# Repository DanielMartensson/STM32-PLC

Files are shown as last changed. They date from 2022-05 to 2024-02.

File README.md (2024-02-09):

# STM32 PLC

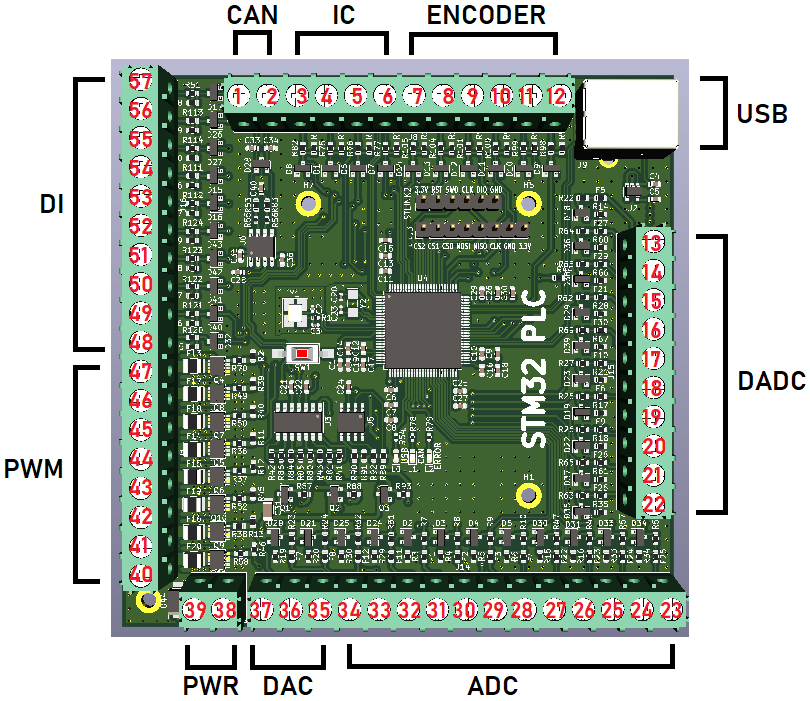
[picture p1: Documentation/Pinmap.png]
a


This project is a PCB bord that has the following measurement and control input/output:

 * 12 x ADC at 16-bit resolution for 0-20mA input with programmable gain
 * 5 x Differential ADC at 16-bit for 0-20mA input with programmable gain
 * 3 x DAC at 12-bit with 0-20mA output
 * 8 x PWM for 0-2.2A with N-channel MOSFET
 * 10 x Digital Input
 * 1 x CAN-bus channel
 * 4 x Input Capture for 0 kHz to 10kHz
 * 3 x Encoder for -32768 to 32767 pulses
 * 1 x USB port for connecting with [OpenSourceLogger](https://github.com/DanielMartensson/OpenSourceLogger) and [GoobySoft](https://github.com/DanielMartensson/GoobySoft)
 * 1 x SPI with 3 chip select for ILI9341 LCD with touch
 * 1 x ST-Link V2 connection
 * 1 x RTC clock with two alarms A(date) and B(week day) and a battery holder so the RTC remembers the date and time

## Protection 
 * All ADC, Digital Input, Differential ADC, Input Capture and Encoder are high voltage protected with PTC(fall current 30mA) fuse + 3.6v zener diode.
 * All PWM and DAC are high voltage protected with N-channel MOSFET and PNP-transistor and OP-amp. 
 * The CAN-bus channel is high voltage peak protected for 3000V under a short time with a TVS-diode. The CAN-bus transmitter itself can hold against -14V to +14V, but the TVS-diode has a limit around 6V. 

## Documentation
The documentation for the pin map can be found in the `Documentation` folder. Also all the article numbers for each component can be found in at the `DAC ADC PWM IO.sch` file in the `PCB` folder. Just double click on a PCB symbol and see the `Mouser Electronics` article number of the electrical component. 

## Calibration
Yes, it's possible to set the calibration to each input in this project. You need to have the ILI9341 touch LCD with SPI bus. Open the `STM32 PLC Pinouts.pdf` and see the connection for the LCD. You can also set the PWM frequency and analog input gain for the ADC and Differential ADC at 16-bit. 

## SAE J1939
The STM32 PLC has internal SAE J1939 protocol. Made from [Open-SAE-J1939](https://github.com/DanielMartensson/Open-SAE-J1939) repository.

## OpenSourceLogger
This is a QT C++ software that you can connect to your STM32 PLC board via the USB and then you can send signals from OpenSourceLogger and recieve signals.
OpenSourceLogger is a very easy to use logging and controlling software and it stores data at a SQL server. 

## GoobySoft
This is a ImGui C++ project that do the same as OpenSourceLogger, but it's much better and have more features. The reason why I moved away from QT C++ to ImGui C++ is because
it's much easier to write a GUI application in C++ by using ImGui instead of QT. With QT, you are stuck with object oriented programming. Everything is a class. 
But for ImGui, you can choose which type of lever you want to code, I prefer C-style C++ code with a small dose of object oriented programming (if needed). 

Consider that I will work on GoobySoft instead of OpenSourceLogger.

## Program 
The STM32 PLC has a lot of functions you can select by touching the LCD. 

 * A:Show measurement and time
 * B:Set analog gain
 * C:Set PWM frequencies
 * D:Set analog input calibration
 * E:Set pulses per encoder revolution
 * F:Set date and time and alarm
 * G:Do a PGN request
 * H:Show ECU addresses
 * I:Commanded address
 * J:Show this ECU DM1 codes
 * K:Show other ECU DM1 codes
 * L:Show this ECU DM2 codes
 * M:Show other ECU DM2 codes
 * N:Show this ECU name
 * O:Show other ECU name
 * P:Show this ECU identifications
 * Q:Show other ECU identifications
 * R:SAE J1939 Auxiliary valve command
 * S:Analog in to PWM
 * T:Analog in to analog out
 * U:About STM32 PLC

## How to build this STM32 PLC

 1. Download this repository
 2. Download & Install KiCad
 3. Open the `PCB` folder and open the `.pro` file with KiCAD and greate a `gerber` file of your own choice
 4. Go to your PCB manufacturer and give them the `gerber` file and let them produce the board for you
 5. Order the eletrical components from `Mouser Electronics`
 6. Once you have the eletrical components and your PCB board, it's time to solder them.
 7. Once the PCB board is finished, then install STM32CubeIDE
 8. Open the `Code` project and import the `.ioc` project file using STM32CubeIDE
 9. Flash the board with the `C` code by using ST-Link V2 connection
 10. Connect the ILI9431 touch LCD and then you are done!

## Software used

 * KiCAD: 6.0.7
 * STM32CubeIDE 1.10.1

## Status of the project
It's done. I don't plan to update this project. Everything is working and it will remain that way.

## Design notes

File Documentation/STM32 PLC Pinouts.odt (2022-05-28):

STM32 PLC Pinouts

# Pin definitions

- CAN = CAN bus channel at 250 kB/s baud rate
- IC = Input capture pulse measurement
- Encoder = Encoder pulse measurement
- DADC = Differential Analog to Digital Converter
- ADC = Analog to Digital Converter
- DAC = Digital to Analog Converter
- PWR = Power supply
- PWM = Pulse with modulation
- DI = Digital input

Pin number | Iinput/Output | Name | Max voltage | Min voltage | Comment | Purpose
1 | Both | CAN High | 14V | -15V | TVS diodes for 30kV | CAN communication
2 | Both | CAN Low | 14V | -15V | TVS diodes for 30kV | CAN communication
3 | Input | IC 0 | 30V | -1V | 16 -bit resolution | Frequency 0 Hz to 10 kHz
4 | Input | IC 1 | 30V | -1V | 16 -bit resolution | Frequency 0 Hz to 10 kHz
5 | Input | IC 2 | 30V | -1V | 16 -bit resolution | Frequency 0 Hz to 10 kHz
6 | Input | IC 3 | 30V | -1V | 16 -bit resolution | Frequency 0 Hz to 10 kHz
7 | Input | Encoder 0 + | 30V | -1V | 16 -bit resolution | Counting -32768 to 32767
8 | Input | Encoder 0 - | 30V | -1V | 16 -bit resolution | Counting -32768 to 32767
9 | Input | Encoder 1 + | 30V | -1V | 16 -bit resolution | Counting -32768 to 32767
10 | Input | Encoder 1 - | 30V | -1V | 16 -bit resolution | Counting -32768 to 32767
11 | Input | Encoder 2 + | 30V | -1V | 16 -bit resolution | Counting -32768 to 32767
12 | Input | Encoder 2 - | 30V | -1V | 16 -bit resolution | Counting -32768 to 32767
13 | Input | DADC 4 - | 30V | -1V | PTC 30mA protection | Measuring -32768 to 32767
14 | Input | DADC 4 + | 30V | -1V | PTC 30mA protection | Measuring -32768 to 32767
15 | Input | DADC 3 - | 30V | -1V | PTC 30mA protection | Measuring -32768 to 32767
16 | Input | DADC 3 + | 30V | -1V | PTC 30mA protection | Measuring -32768 to 32767
17 | Input | DADC 2 - | 30V | -1V | PTC 30mA protection | Measuring -32768 to 32767
18 | Input | DADC 2 + | 30V | -1V | PTC 30mA protection | Measuring -32768 to 32767
19 | Input | DADC 1 - | 30V | -1V | PTC 30mA protection | Measuring -32768 to 32767
20 | Input | DADC 1 + | 30V | -1V | PTC 30mA protection | Measuring -32768 to 32767
21 | Input | DADC 0 - | 30V | -1V | PTC 30mA protection | Measuring -32768 to 32767
22 | Input | DADC 0 + | 30V | -1V | PTC 30mA protection | Measuring -32768 to 32767
23 | Input | ADC 11 | 30V | -1V | PTC 30mA protection | Measuring 0 to 65535
24 | Input | ADC 10 | 30V | -1V | PTC 30mA protection | Measuring 0 to 65535
25 | Input | ADC 9 | 30V | -1V | PTC 30mA protection | Measuring 0 to 65535
26 | Input | ADC 8 | 30V | -1V | PTC 30mA protection | Measuring 0 to 65535
27 | Input | ADC 7 | 30V | -1V | PTC 30mA protection | Measuring 0 to 65535
28 | Input | ADC 6 | 30V | -1V | PTC 30mA protection | Measuring 0 to 65535
29 | Input | ADC 5 | 30V | -1V | PTC 30mA protection | Measuring 0 to 65535
30 | Input | ADC 4 | 30V | -1V | PTC 30mA protection | Measuring 0 to 65535
31 | Input | ADC 3 | 30V | -1V | PTC 30mA protection | Measuring 0 to 65535
32 | Input | ADC 2 | 30V | -1V | PTC 30mA protection | Measuring 0 to 65535
33 | Input | ADC 1 | 30V | -1V | PTC 30mA protection | Measuring 0 to 65535
34 | Input | ADC 0 | 30V | -1V | PTC 30mA protection | Measuring 0 to 65535
35 | Output | DAC 2 | 30V | -1V | 12-bit resolution | 0 to 20mA output
36 | Output | DAC 1 | 30V | -1V | 12-bit resolution | 0 to 20mA output
37 | Output | DAC 0 | 30V | -1V | 12-bit resolution | 0 to 20mA output
38 | Input | VDC | 32V | -1V | | Power supply for the 0 to 20 mA output
39 | Output | GND | 0V | 0V | | Ground
40 | Input(Open drain) | PWM 7 | 30V | -1V | Use protection diode if solenoid is applied | MOSFET N-Channel PWM open drain
41 | Input(Open drain) | PWM 6 | 30V | -1V | Use protection diode if solenoid is applied | MOSFET N-Channel PWM open drain
42 | Input(Open drain) | PWM 5 | 30V | -1V | Use protection diode if solenoid is applied | MOSFET N-Channel PWM open drain
43 | Input(Open drain) | PWM 4 | 30V | -1V | Use protection diode if solenoid is applied | MOSFET N-Channel PWM open drain
44 | Input(Open drain) | PWM 3 | 30V | -1V | Use protection diode if solenoid is applied | MOSFET N-Channel PWM open drain
45 | Input(Open drain) | PWM 2 | 30V | -1V | Use protection diode if solenoid is applied | MOSFET N-Channel PWM open drain
46 | Input(Open drain) | PWM 1 | 30V | -1V | Use protection diode if solenoid is applied | MOSFET N-Channel PWM open drain
47 | Input(Open drain) | PWM 0 | 30V | -1V | Use protection diode if solenoid is applied | MOSFET N-Channel PWM open drain
48 | Input | DI 9 | 30V | -1V | Zener diode protection | Measuring 0 to 1
49 | Input | DI 8 | 30V | -1V | | Measuring 0 to 1
50 | Input | DI 7 | 30V | -1V | | Measuring 0 to 1
51 | Input | DI 6 | 30V | -1V | | Measuring 0 to 1
52 | Input | DI 5 | 30V | -1V | | Measuring 0 to 1
53 | Input | DI 4 | 30V | -1V | | Measuring 0 to 1
54 | Input | DI 3 | 30V | -1V | | Measuring 0 to 1
55 | Input | DI 2 | 30V | -1V | | Measuring 0 to 1
56 | Input | DI 1 | 30V | -1V | | Measuring 0 to 1
57 | Input | DI 0 | 30V | -1V | | Measuring 0 to 1


# LCD ILI9341 with SPI bus

Notice that the CLK for the ST-LINK V2 and the other CLK pin is not the same! The other CLK pin is the SPI clock pin.

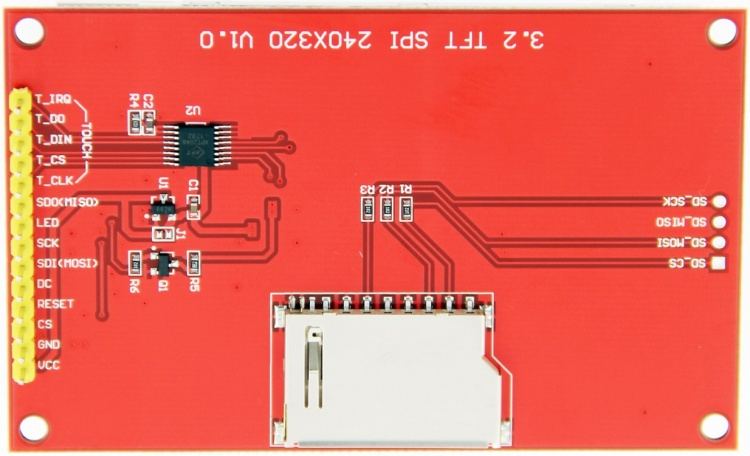
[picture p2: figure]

Connect | To | Comment
T_IRQ | | Leave floating
T_DO | SDO<MISO> | On the LCD
D_DIN | SDI<MOSI> | On the LCD
T_CS | CS2 | On the STM32 PLC
T_CLK | SCK | On the LCD
SDO<MISO> | MISO | On the STM32 PLC
LED | VCC | On the LCD
SCK | CLK | On the STM32 PLC
SDI<MOSI> | MOSI | On the STM32 PLC
DC | CS1 | On the STM32 PLC
RESET | VCC | On the LCD
CS | CS0 | On the STM32 PLC
GND | GND | On the STM32 PLC
VCC | 3.3V | On the STM32 PLC

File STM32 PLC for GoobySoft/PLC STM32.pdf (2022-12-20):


20/12/2022

PLC STM32 Project
Configuration Report

## 1. Description

### 1.1. Project

Project Name | PLC STM32
Board Name | custom
Generated with: | STM32CubeMX 6.6.1
Date | 12/20/2022

### 1.2. MCU

MCU Series | STM32F3
MCU Line | STM32F373
MCU name | STM32F373VBTx
MCU Package | LQFP100
MCU Pin number | 100

### 1.3. Core(s) information

Core(s) | Arm Cortex-M4

## 2. Pinout Configuration

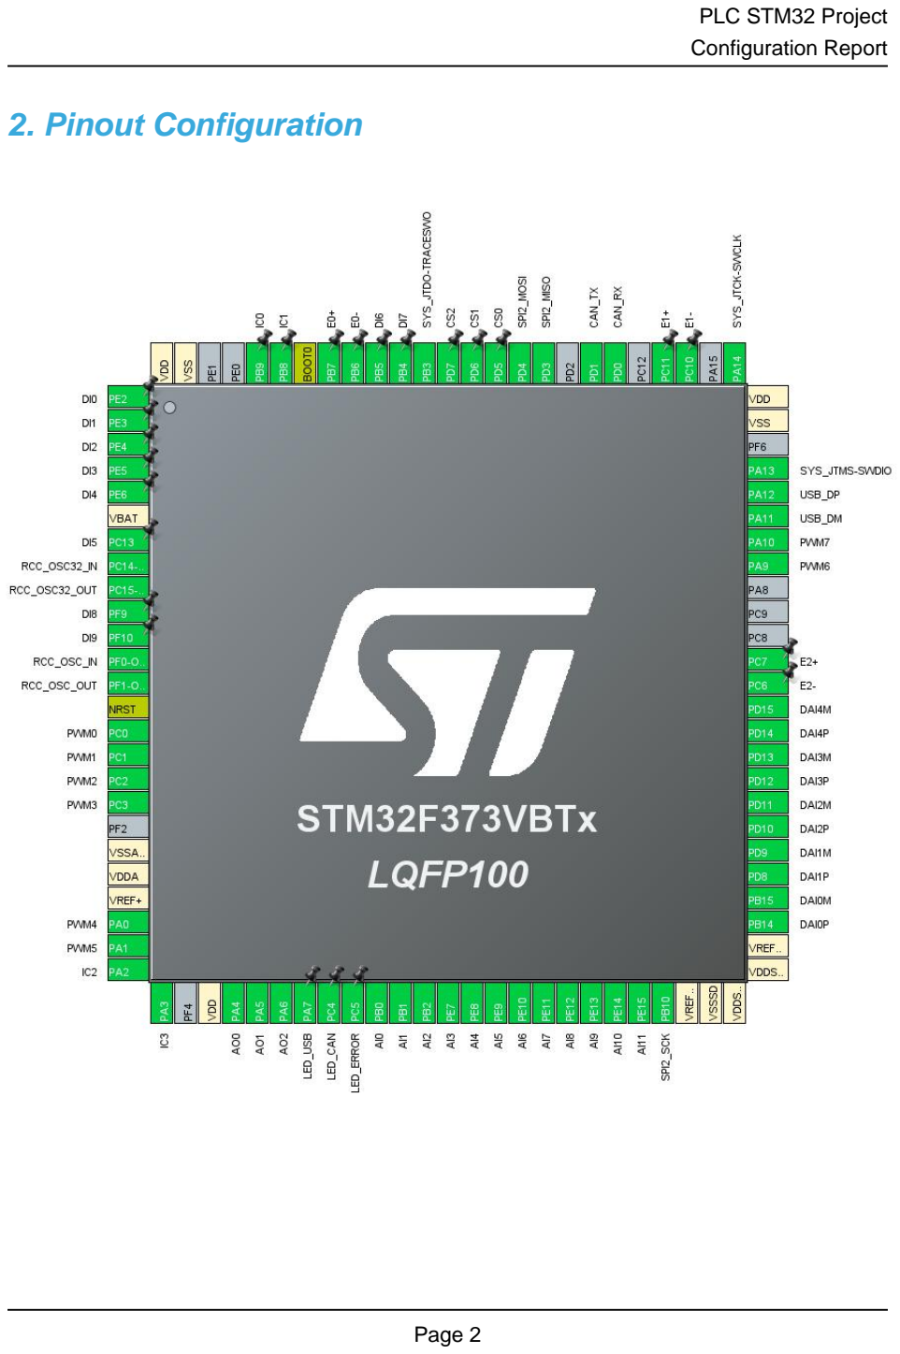
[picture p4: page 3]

## 3. Pins Configuration

Pin Number LQFP100 | Pin Name (function after reset) | Pin Type | Alternate Function(s) | Label
1 | PE2 * | I/O | GPIO_Input | DI0
2 | PE3 * | I/O | GPIO_Input | DI1
3 | PE4 * | I/O | GPIO_Input | DI2
4 | PE5 * | I/O | GPIO_Input | DI3
5 | PE6 * | I/O | GPIO_Input | DI4
6 | VBAT | Power
7 | PC13 * | I/O | GPIO_Input | DI5
8 | PC14-OSC32_IN | I/O | RCC_OSC32_IN
9 | PC15-OSC32_OUT | I/O | RCC_OSC32_OUT
10 | PF9 * | I/O | GPIO_Input | DI8
11 | PF10 * | I/O | GPIO_Input | DI9
12 | PF0-OSC_IN | I/O | RCC_OSC_IN
13 | PF1-OSC_OUT | I/O | RCC_OSC_OUT
14 | NRST | Reset
15 | PC0 | I/O | TIM5_CH1 | PWM0
16 | PC1 | I/O | TIM5_CH2 | PWM1
17 | PC2 | I/O | TIM5_CH3 | PWM2
18 | PC3 | I/O | TIM5_CH4 | PWM3
20 | VSSA/VREF- | Power
21 | VDDA | Power
22 | VREF+ | Power
23 | PA0 | I/O | TIM2_CH1 | PWM4
24 | PA1 | I/O | TIM2_CH2 | PWM5
25 | PA2 | I/O | TIM15_CH1 | IC2
26 | PA3 | I/O | TIM15_CH2 | IC3
28 | VDD | Power
29 | PA4 | I/O | DAC1_OUT1 | AO0
30 | PA5 | I/O | DAC1_OUT2 | AO1
31 | PA6 | I/O | DAC2_OUT1 | AO2
32 | PA7 * | I/O | GPIO_Output | LED_USB
33 | PC4 * | I/O | GPIO_Output | LED_CAN
34 | PC5 * | I/O | GPIO_Output | LED_ERROR
35 | PB0 | I/O | SDADC1_AIN6P | AI0
36 | PB1 | I/O | SDADC1_AIN5P | AI1
37 | PB2 | I/O | SDADC1_AIN4P | AI2
38 | PE7 | I/O | SDADC1_AIN3P | AI3

Pin Number LQFP100 | Pin Name (function after reset) | Pin Type | Alternate Function(s) | Label
39 | PE8 | I/O | SDADC1_AIN8P | AI4
40 | PE9 | I/O | SDADC1_AIN7P | AI5
41 | PE10 | I/O | SDADC1_AIN2P | AI6
42 | PE11 | I/O | SDADC1_AIN1P | AI7
43 | PE12 | I/O | SDADC1_AIN0P | AI8
44 | PE13 | I/O | SDADC2_AIN2P | AI9
45 | PE14 | I/O | SDADC2_AIN1P | AI10
46 | PE15 | I/O | SDADC2_AIN0P | AI11
47 | PB10 | I/O | SPI2_SCK
48 | VREFSD- | Power
49 | VSSSD | Power
50 | VDDSD12 | Power
51 | VDDSD3 | Power
52 | VREFSD+ | Power
53 | PB14 | I/O | SDADC3_AIN8P | DAI0P
54 | PB15 | I/O | SDADC3_AIN8M | DAI0M
55 | PD8 | I/O | SDADC3_AIN6P | DAI1P
56 | PD9 | I/O | SDADC3_AIN6M | DAI1M
57 | PD10 | I/O | SDADC3_AIN4P | DAI2P
58 | PD11 | I/O | SDADC3_AIN4M | DAI2M
59 | PD12 | I/O | SDADC3_AIN2P | DAI3P
60 | PD13 | I/O | SDADC3_AIN2M | DAI3M
61 | PD14 | I/O | SDADC3_AIN0P | DAI4P
62 | PD15 | I/O | SDADC3_AIN0M | DAI4M
63 | PC6 | I/O | TIM3_CH1 | E2-
64 | PC7 | I/O | TIM3_CH2 | E2+
68 | PA9 | I/O | TIM2_CH3 | PWM6
69 | PA10 | I/O | TIM2_CH4 | PWM7
70 | PA11 | I/O | USB_DM
71 | PA12 | I/O | USB_DP
72 | PA13 | I/O | SYS_JTMS-SWDIO
74 | VSS | Power
75 | VDD | Power
76 | PA14 | I/O | SYS_JTCK-SWCLK
78 | PC10 | I/O | TIM19_CH1 | E1-
79 | PC11 | I/O | TIM19_CH2 | E1+
81 | PD0 | I/O | CAN_RX
82 | PD1 | I/O | CAN_TX
84 | PD3 | I/O | SPI2_MISO

Pin Number LQFP100 | Pin Name (function after reset) | Pin Type | Alternate Function(s) | Label
85 | PD4 | I/O | SPI2_MOSI
86 | PD5 * | I/O | GPIO_Output | CS0
87 | PD6 * | I/O | GPIO_Output | CS1
88 | PD7 * | I/O | GPIO_Output | CS2
89 | PB3 | I/O | SYS_JTDO-TRACESWO
90 | PB4 * | I/O | GPIO_Input | DI7
91 | PB5 * | I/O | GPIO_Input | DI6
92 | PB6 | I/O | TIM4_CH1 | E0-
93 | PB7 | I/O | TIM4_CH2 | E0+
94 | BOOT0 | Boot
95 | PB8 | I/O | TIM16_CH1 | IC1
96 | PB9 | I/O | TIM17_CH1 | IC0
99 | VSS | Power
100 | VDD | Power

* The pin is affected with an I/O function

## 4. Clock Tree Configuration

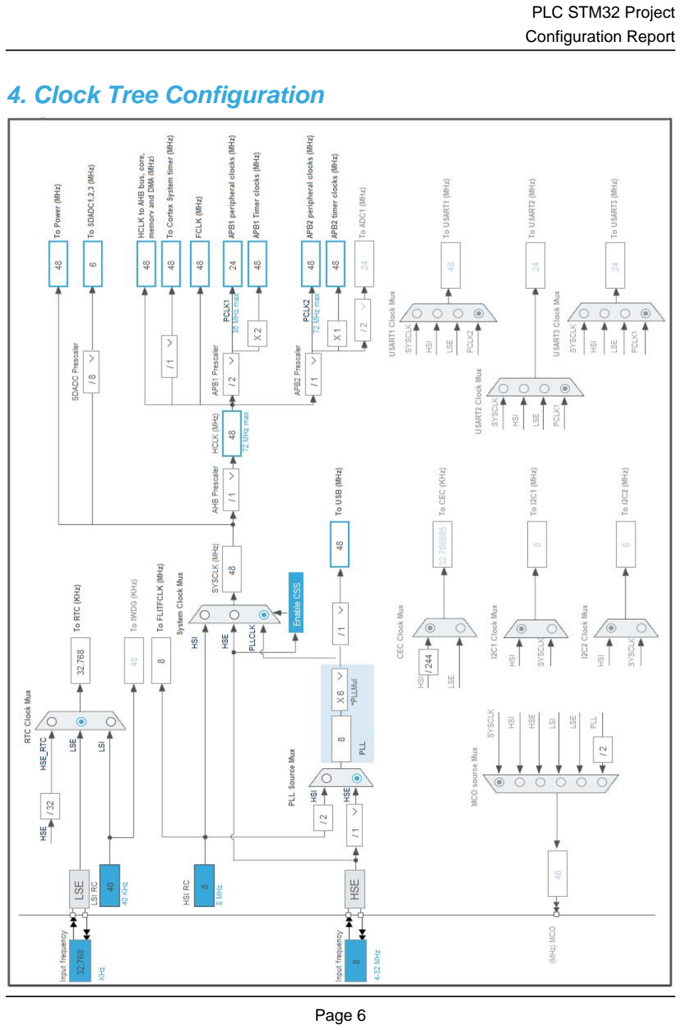
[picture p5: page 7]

## 5. Software Project

### 5.1. Project Settings

Name | Value
Project Name | PLC STM32
Project Folder | C:\Users\dmn\STM32Cube\Projekt\PLC STM32
Toolchain / IDE | STM32CubeIDE
Firmware Package Name and Version | STM32Cube FW_F3 V1.11.3
Application Structure | Advanced
Generate Under Root | Yes
Do not generate the main() | No
Minimum Heap Size | 0x200
Minimum Stack Size | 0x400

### 5.2. Code Generation Settings

Name | Value
STM32Cube MCU packages and embedded software | Copy only the necessary library files
Generate peripheral initialization as a pair of '.c/.h' files | No
Backup previously generated files when re-generating | No
Keep User Code when re-generating | Yes
Delete previously generated files when not re-generated | Yes
Set all free pins as analog (to optimize the power consumption) | No
Enable Full Assert | No

### 5.3. Advanced Settings - Generated Function Calls

Rank | Function Name | Peripheral Instance Name
1 | MX_GPIO_Init | GPIO
2 | SystemClock_Config | RCC
3 | MX_DAC1_Init | DAC1
4 | MX_DAC2_Init | DAC2
5 | MX_TIM2_Init | TIM2
6 | MX_TIM5_Init | TIM5
7 | MX_TIM4_Init | TIM4
8 | MX_SDADC1_Init | SDADC1
9 | MX_SDADC2_Init | SDADC2
10 | MX_SDADC3_Init | SDADC3
11 | MX_CAN_Init | CAN

Rank | Function Name | Peripheral Instance Name
12 | MX_TIM6_Init | TIM6
13 | MX_TIM12_Init | TIM12
14 | MX_TIM13_Init | TIM13
15 | MX_TIM16_Init | TIM16
16 | MX_USB_DEVICE_Init | USB_DEVICE
17 | MX_TIM17_Init | TIM17
18 | MX_DMA_Init | DMA
19 | MX_TIM19_Init | TIM19
20 | MX_TIM3_Init | TIM3
21 | MX_TIM15_Init | TIM15
22 | MX_SPI2_Init | SPI2
23 | MX_RTC_Init | RTC

## 6. Power Consumption Calculator report

### 6.1. Microcontroller Selection

Series | STM32F3
Line | STM32F373
MCU | STM32F373VBTx
Datasheet | DS8845_Rev7

### 6.2. Parameter Selection

Temperature | 25
Vdd | 3.6

### 6.3. Battery Selection

Battery | Li-SOCL2(A3400)
Capacity | 3400.0 mAh
Self Discharge | 0.08 %/month
Nominal Voltage | 3.6 V
Max Cont Current | 100.0 mA
Max Pulse Current | 200.0 mA
Cells in series | 1
Cells in parallel | 1

### 6.4. Sequence

Step | Step1 | Step2
Mode | RUN | STOP
Vdd | 3.6 | 3.6
Voltage Source | Battery | Battery
Range | No Scale | No Scale
Fetch Type | RAM | n/a
CPU Frequency | 72 MHz | 0 Hz
Clock Configuration | HSEBYP PLL | Regulator_LP
Clock Source Frequency | 8 MHz | 0 Hz
Peripherals
Additional Cons. | 0 mA | 0 mA
Average Current | 30.25 mA | 10.9 µA
Duration | 0.1 ms | 0.9 ms
DMIPS | 90.0 | 0.0
Ta Max | 99.99 | 105
Category | In DS Table | In DS Table

### 6.5. Results

Sequence Time | 1 ms | Average Current | 3.03 mA
Battery Life | 1 month, 16 days, 4 hours | Average DMIPS | 90.0 DMIPS

### 6.6. Chart

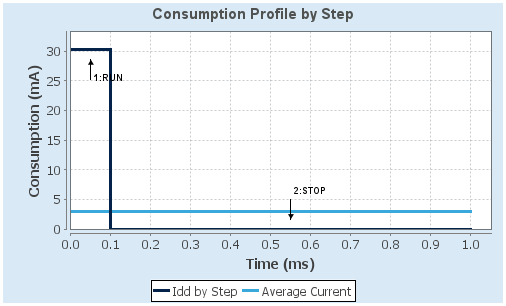
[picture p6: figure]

## 7. Peripherals and Middlewares Configuration

### 7.1. CAN

mode: Activated
7.1.1. Parameter Settings:

Bit Timings Parameters:

Prescaler (for Time Quantum) | 12 *
Time Quantum | 500.0 *
Time Quanta in Bit Segment 1 | 6 Times *
Time Quanta in Bit Segment 2 | 1 Time
Time for one Bit | 4000 *
Baud Rate | 250000 *
ReSynchronization Jump Width | 1 Time
Basic Parameters:
Time Triggered Communication Mode | Disable
Automatic Bus-Off Management | Disable
Automatic Wake-Up Mode | Disable
Automatic Retransmission | Disable
Receive Fifo Locked Mode | Disable
Transmit Fifo Priority | Disable
Advanced Parameters:
Operating Mode | Normal

### 7.2. DAC1

mode: OUT1 Configuration
mode: OUT2 Configuration
7.2.1. Parameter Settings:

DAC Out1 Settings:

Output Buffer | Enable
Trigger | Timer 6 Trigger Out event *
Wave generation mode | Disabled
DAC Out2 Settings:
Output Buffer | Enable
Trigger | Timer 6 Trigger Out event *
Wave generation mode | Disabled

### 7.3. DAC2

mode: OUT1 Configuration
7.3.1. Parameter Settings:

DAC Out1 Settings:

Output Buffer | Enable
Trigger | Timer 6 Trigger Out event *

### 7.4. RCC

High Speed Clock (HSE): Crystal/Ceramic Resonator Low Speed Clock (LSE) : Crystal/Ceramic Resonator
7.4.1. Parameter Settings:

System Parameters:

VDD voltage (V) | 3.3
Prefetch Buffer | Enabled
Flash Latency(WS) | 1 WS (2 CPU cycle)
RCC Parameters:
HSI Calibration Value | 16
HSE Startup Timout Value (ms) | 100
LSE Startup Timout Value (ms) | 10000 *
LSE Drive Capability | LSE oscillator low drive capability

### 7.5. RTC

mode: Activate Clock Source
mode: Activate Calendar
Alarm A: Internal Alarm A
Alarm B: Internal Alarm B
7.5.1. Parameter Settings:

General:

Hour Format | Hourformat 24
Asynchronous Predivider value | 127

Synchronous Predivider value | 255
Calendar Time:
Data Format | BCD data format
Hours | 0
Minutes | 0
Seconds | 0
Day Light Saving: value of hour adjustment | Daylightsaving None
Store Operation | Storeoperation Reset
Calendar Date:
Week Day | Monday
Month | January
Date | 1
Year | 0
Alarm A:
Hours | 0
Minutes | 0
Seconds | 0
Sub Seconds | 0
Alarm Mask Date Week day | Disable
Alarm Mask Hours | Disable
Alarm Mask Minutes | Disable
Alarm Mask Seconds | Disable
Alarm Sub Second Mask | All Alarm SS fields are masked.
Alarm Date Week Day Sel | Date
Alarm Date | 1
Alarm B:
Hours | 0
Minutes | 0
Seconds | 0
Sub Seconds | 0
Alarm Mask Date Week day | Disable
Alarm Mask Hours | Disable
Alarm Mask Minutes | Disable
Alarm Mask Seconds | Disable
Alarm Sub Second Mask | All Alarm SS fields are masked.
Alarm Date Week Day Sel | Weekday *
Alarm Week Day | Monday

### 7.6. SDADC1

IN0: IN0-Single-Ended zero reference IN1: IN1-Single-Ended zero reference IN2: IN2-Single-Ended zero reference IN3: IN3-Single-Ended zero reference IN4: IN4-Single-Ended zero reference IN5: IN5-Single-Ended zero reference IN6: IN6-Single-Ended zero reference IN7: IN7-Single-Ended zero reference IN8: IN8-Single-Ended zero reference mode: Conversion Configuration 0 mode: Conversion Configuration 1 mode: Conversion Configuration 2
7.6.1. Parameter Settings:

General Settings:

Low Power Mode | None
Fast Conversion Mode | Disable
Slow Clock Mode | Disable
Reference Voltage | Forced externally using VREF pin
Conversion Configuration 0:
Input Mode | Single-ended zero-volt reference mode *
Gain | equal to 1
Common Mode | SDADC VSSA
Offset | 0
Conversion Configuration 1:
Input Mode | Single-ended zero-volt reference mode *
Gain | equal to 1
Common Mode | SDADC VSSA
Offset | 0
Conversion Configuration 2:
Input Mode | Single-ended zero-volt reference mode *
Gain | equal to 1
Common Mode | SDADC VSSA
Offset | 0
SDADC Regular Conversions Settings:
Enable Regular Conversion | Disable
SDADC Injected Conversions Settings:
Enable Injected Conversion | Enable *

Number of Channels To be converted | 9 *
Trigger type | External trigger *
External Trigger Edge | Rising edge
External Trigger source | Timer 13 Capture Compare 1
Injected Delay | Disable
Injected Multimode type | Disable
Continuous Mode | Enabled *
Channel Configuration | 1
Channel | Channel 0
Configuration Index | Configuration 2 *
Channel Configuration | 2 *
Channel | Channel 1
Configuration Index | Configuration 2 *
Channel Configuration | 3 *
Channel | Channel 2
Configuration Index | Configuration 1 *
Channel Configuration | 4 *
Channel | Channel 3
Configuration Index | Configuration 1 *
Channel Configuration | 5 *
Channel | Channel 4
Configuration Index | Configuration 0
Channel Configuration | 6 *
Channel | Channel 5
Configuration Index | Configuration 0
Channel Configuration | 7 *
Channel | Channel 6
Configuration Index | Configuration 0
Channel Configuration | 8 *
Channel | Channel 7
Configuration Index | Configuration 1 *
Channel Configuration | 9 *
Channel | Channel 8
Configuration Index | Configuration 1 *

### 7.7. SDADC2

IN0: IN0-Single-Ended zero reference

IN1: IN1-Single-Ended zero reference IN2: IN2-Single-Ended zero reference mode: Conversion Configuration 0 mode: Conversion Configuration 1 mode: Conversion Configuration 2
7.7.1. Parameter Settings:

General Settings:

Low Power Mode | None
Fast Conversion Mode | Disable
Slow Clock Mode | Disable
Reference Voltage | Forced externally using VREF pin
Conversion Configuration 0:
Input Mode | Single-ended zero-volt reference mode *
Gain | equal to 1
Common Mode | SDADC VSSA
Offset | 0
Conversion Configuration 1:
Input Mode | Single-ended zero-volt reference mode *
Gain | equal to 1
Common Mode | SDADC VSSA
Offset | 0
Conversion Configuration 2:
Input Mode | Single-ended zero-volt reference mode *
Gain | equal to 1
Common Mode | SDADC VSSA
Offset | 0
SDADC Regular Conversions Settings:
Enable Regular Conversion | Disable
SDADC Injected Conversions Settings:
Enable Injected Conversion | Enable *
Number of Channels To be converted | 3 *
Trigger type | External trigger *
External Trigger Edge | Rising edge
External Trigger source | Timer 12 Capture Compare 1 *
Injected Delay | Disable
Continuous Mode | Enabled *
Channel Configuration | 1
Channel | Channel 0

Configuration Index | Configuration 2 *
Channel Configuration | 2 *
Channel | Channel 1
Configuration Index | Configuration 1 *
Channel Configuration | 3 *
Channel | Channel 2
Configuration Index | Configuration 0

### 7.8. SDADC3

IN0: IN0-Differential
IN2: IN2-Differential
IN4: IN4-Differential
IN6: IN6-Differential
IN8: IN8-Differential
mode: Conversion Configuration 0 mode: Conversion Configuration 1 mode: Conversion Configuration 2
7.8.1. Parameter Settings:

General Settings:

Low Power Mode | None
Fast Conversion Mode | Disable
Slow Clock Mode | Disable
Reference Voltage | Forced externally using VREF pin
Conversion Configuration 0:
Input Mode | Differential mode
Gain | equal to 1
Common Mode | SDADC VSSA
Offset | 0
Conversion Configuration 1:
Input Mode | Differential mode
Gain | equal to 1
Common Mode | SDADC VSSA
Offset | 0
Conversion Configuration 2:
Input Mode | Differential mode
Gain | equal to 1
Common Mode | SDADC VSSA

Offset | 0
SDADC Regular Conversions Settings:
Enable Regular Conversion | Disable
SDADC Injected Conversions Settings:
Enable Injected Conversion | Enable *
Number of Channels To be converted | 5 *
Trigger type | External trigger *
External Trigger Edge | Rising edge
External Trigger source | Timer 12 Capture Compare 2 *
Injected Delay | Disable
Continuous Mode | Enabled *
Channel Configuration | 1
Channel | Channel 0
Configuration Index | Configuration 2 *
Channel Configuration | 2 *
Channel | Channel 2
Configuration Index | Configuration 1 *
Channel Configuration | 3 *
Channel | Channel 4
Configuration Index | Configuration 1 *
Channel Configuration | 4 *
Channel | Channel 6
Configuration Index | Configuration 0
Channel Configuration | 5 *
Channel | Channel 8
Configuration Index | Configuration 0

### 7.9. SPI2

Mode: Full-Duplex Master
7.9.1. Parameter Settings:

Basic Parameters:

Frame Format | Motorola
Data Size | 8 Bits *
First Bit | MSB First
Clock Parameters:
Prescaler (for Baud Rate) | 4 *

Baud Rate | 6.0 MBits/s *
Clock Polarity (CPOL) | Low
Clock Phase (CPHA) | 1 Edge
Advanced Parameters:
CRC Calculation | Disabled
NSSP Mode | Enabled
NSS Signal Type | Software

### 7.10. SYS

Debug: Trace Asynchronous Sw Timebase Source: SysTick

### 7.11. TIM2

Clock Source : Internal Clock Channel1: PWM Generation CH1 Channel2: PWM Generation CH2 Channel3: PWM Generation CH3 Channel4: PWM Generation CH4
7.11.1. Parameter Settings:

Counter Settings:

Prescaler (PSC - 16 bits value) | 0
Counter Mode | Up
Counter Period (AutoReload Register - 32 bits value ) | 0xffff *
Internal Clock Division (CKD) | No Division
auto-reload preload | Disable
Trigger Output (TRGO) Parameters:
Master/Slave Mode (MSM bit) | Disable (Trigger input effect not delayed)
Trigger Event Selection | Reset (UG bit from TIMx_EGR)
PWM Generation Channel 1:
Mode | PWM mode 1
Pulse (32 bits value) | 0
Output compare preload | Enable
Fast Mode | Disable
CH Polarity | High
PWM Generation Channel 2:
Mode | PWM mode 1
Pulse (32 bits value) | 0

Output compare preload | Enable
Fast Mode | Disable
CH Polarity | High
PWM Generation Channel 3:
Mode | PWM mode 1
Pulse (32 bits value) | 0
Output compare preload | Enable
Fast Mode | Disable
CH Polarity | High
PWM Generation Channel 4:
Mode | PWM mode 1
Pulse (32 bits value) | 0
Output compare preload | Enable
Fast Mode | Disable
CH Polarity | High

### 7.12. TIM3

Combined Channels: Encoder Mode
7.12.1. Parameter Settings:

Counter Settings:

Prescaler (PSC - 16 bits value) | 0
Counter Mode | Up
Counter Period (AutoReload Register - 16 bits value ) | 65535
Internal Clock Division (CKD) | No Division
auto-reload preload | Disable
Trigger Output (TRGO) Parameters:
Master/Slave Mode (MSM bit) | Disable (Trigger input effect not delayed)
Trigger Event Selection | Reset (UG bit from TIMx_EGR)
Encoder:
Encoder Mode | Encoder Mode TI1 and TI2 *

____ Parameters for Channel 1 ____
Polarity | Rising Edge
IC Selection | Direct
Prescaler Division Ratio | No division
Input Filter | 0
____ Parameters for Channel 2 ____
Polarity | Rising Edge
IC Selection | Direct
Prescaler Division Ratio | No division

Input Filter | 0

### 7.13. TIM4

Combined Channels: Encoder Mode
7.13.1. Parameter Settings:

Counter Settings:

Prescaler (PSC - 16 bits value) | 0
Counter Mode | Up
Counter Period (AutoReload Register - 16 bits value ) | 65535
Internal Clock Division (CKD) | No Division
auto-reload preload | Disable
Trigger Output (TRGO) Parameters:
Master/Slave Mode (MSM bit) | Disable (Trigger input effect not delayed)
Trigger Event Selection | Reset (UG bit from TIMx_EGR)
Encoder:
Encoder Mode | Encoder Mode TI1 and TI2 *

____ Parameters for Channel 1 ____
Polarity | Rising Edge
IC Selection | Direct
Prescaler Division Ratio | No division
Input Filter | 0
____ Parameters for Channel 2 ____
Polarity | Rising Edge
IC Selection | Direct
Prescaler Division Ratio | No division
Input Filter | 0

### 7.14. TIM5

Clock Source : Internal Clock Channel1: PWM Generation CH1 Channel2: PWM Generation CH2 Channel3: PWM Generation CH3 Channel4: PWM Generation CH4
7.14.1. Parameter Settings:

Counter Settings:

Prescaler (PSC - 16 bits value) | 0
Counter Mode | Up
Counter Period (AutoReload Register - 32 bits value ) | 0xffff *
Internal Clock Division (CKD) | No Division
auto-reload preload | Disable
Trigger Output (TRGO) Parameters:
Master/Slave Mode (MSM bit) | Disable (Trigger input effect not delayed)
Trigger Event Selection | Reset (UG bit from TIMx_EGR)
PWM Generation Channel 1:
Mode | PWM mode 1
Pulse (32 bits value) | 0
Output compare preload | Enable
Fast Mode | Disable
CH Polarity | High
PWM Generation Channel 2:
Mode | PWM mode 1
Pulse (32 bits value) | 0
Output compare preload | Enable
Fast Mode | Disable
CH Polarity | High
PWM Generation Channel 3:
Mode | PWM mode 1
Pulse (32 bits value) | 0
Output compare preload | Enable
Fast Mode | Disable
CH Polarity | High
PWM Generation Channel 4:
Mode | PWM mode 1
Pulse (32 bits value) | 0
Output compare preload | Enable
Fast Mode | Disable
CH Polarity | High

### 7.15. TIM6

mode: Activated
7.15.1. Parameter Settings:

Counter Settings:

Prescaler (PSC - 16 bits value) | 99 *

Counter Mode | Up
Counter Period (AutoReload Register - 16 bits value ) | 0xbb80 *
auto-reload preload | Disable
Trigger Output (TRGO) Parameters:
Trigger Event Selection | Update Event *

### 7.16. TIM12

mode: Clock Source
Channel1: Output Compare No Output Channel2: Output Compare No Output
7.16.1. Parameter Settings:

Counter Settings:

Prescaler (PSC - 16 bits value) | 99 *
Counter Mode | Up
Counter Period (AutoReload Register - 16 bits value ) | 4800 *
Internal Clock Division (CKD) | No Division
auto-reload preload | Disable
Output Compare No Output Channel 1:
Mode | Toggle on match *
Pulse (16 bits value) | 0
Output compare preload | Disable
CH Polarity | High
Output Compare No Output Channel 2:
Mode | Toggle on match *
Pulse (16 bits value) | 0
Output compare preload | Disable
CH Polarity | High

### 7.17. TIM13

mode: Activated
Channel1: Output Compare No Output
7.17.1. Parameter Settings:

Counter Settings:

Prescaler (PSC - 16 bits value) | 99 *

Counter Mode | Up
Counter Period (AutoReload Register - 16 bits value ) | 4800 *
Internal Clock Division (CKD) | No Division
auto-reload preload | Disable
Output Compare No Output Channel 1:
Mode | Toggle on match *
Pulse (16 bits value) | 0
Output compare preload | Disable
CH Polarity | High

### 7.18. TIM15

mode: Clock Source
Channel1: Input Capture direct mode Channel2: Input Capture direct mode
7.18.1. Parameter Settings:

Counter Settings:

Prescaler (PSC - 16 bits value) | 4799 *
Counter Mode | Up
Counter Period (AutoReload Register - 16 bits value ) | 0xffff
Internal Clock Division (CKD) | No Division
Repetition Counter (RCR - 8 bits value) | 0
auto-reload preload | Disable
Trigger Output (TRGO) Parameters:
Master/Slave Mode (MSM bit) | Disable (Trigger input effect not delayed)
Trigger Event Selection | Reset (UG bit from TIMx_EGR)
Input Capture Channel 1:
Polarity Selection | Rising Edge
IC Selection | Direct
Prescaler Division Ratio | No division
Input Filter (4 bits value) | 0
Input Capture Channel 2:
Polarity Selection | Rising Edge
IC Selection | Direct
Prescaler Division Ratio | No division
Input Filter (4 bits value) | 0

### 7.19. TIM16

mode: Activated
Channel1: Input Capture direct mode
7.19.1. Parameter Settings:

Counter Settings:

Prescaler (PSC - 16 bits value) | 4799 *
Counter Mode | Up
Counter Period (AutoReload Register - 16 bits value ) | 0xffff
Internal Clock Division (CKD) | No Division
Repetition Counter (RCR - 8 bits value) | 0
auto-reload preload | Disable
Input Capture Channel 1:
Polarity Selection | Rising Edge
IC Selection | Direct
Prescaler Division Ratio | No division
Input Filter (4 bits value) | 0

### 7.20. TIM17

mode: Activated
Channel1: Input Capture direct mode
7.20.1. Parameter Settings:

Counter Settings:

Prescaler (PSC - 16 bits value) | 4799 *
Counter Mode | Up
Counter Period (AutoReload Register - 16 bits value ) | 0xffff
Internal Clock Division (CKD) | No Division
Repetition Counter (RCR - 8 bits value) | 0
auto-reload preload | Disable
Input Capture Channel 1:
Polarity Selection | Rising Edge
IC Selection | Direct
Prescaler Division Ratio | No division
Input Filter (4 bits value) | 0

### 7.21. TIM19

Combined Channels: Encoder Mode
7.21.1. Parameter Settings:

Counter Settings:

Prescaler (PSC - 16 bits value) | 0
Counter Mode | Up
Counter Period (AutoReload Register - 16 bits value ) | 65535
Internal Clock Division (CKD) | No Division
auto-reload preload | Disable
Trigger Output (TRGO) Parameters:
Master/Slave Mode (MSM bit) | Disable (Trigger input effect not delayed)
Trigger Event Selection | Reset (UG bit from TIMx_EGR)
Encoder:
Encoder Mode | Encoder Mode TI1 and TI2 *

____ Parameters for Channel 1 ____
Polarity | Rising Edge
IC Selection | Direct
Prescaler Division Ratio | No division
Input Filter | 0
____ Parameters for Channel 2 ____
Polarity | Rising Edge
IC Selection | Direct
Prescaler Division Ratio | No division
Input Filter | 0

### 7.22. USB

mode: Device (FS)
7.22.1. Parameter Settings:

Basic Parameters:

Speed | Full Speed 12MBit/s
Physical interface | Internal Phy
Power Parameters:
Low Power | Disabled
Battery Charging | Disabled

### 7.23. USB_DEVICE

Class For FS IP: Communication Device Class (Virtual Port Com)
7.23.1. Parameter Settings:

Basic Parameters:

USBD_MAX_NUM_INTERFACES (Maximum number of supported interfaces) | 1
USBD_MAX_NUM_CONFIGURATION (Maximum number of supported configuration) | 1
USBD_MAX_STR_DESC_SIZ (Maximum size for the string descriptors) | 512
USBD_SELF_POWERED (Enabled self power) | Disabled *
USBD_DEBUG_LEVEL (USBD Debug Level) | 0: No debug message
Class Parameters:
USB CDC Rx Buffer Size | 1000
USB CDC Tx Buffer Size | 1000
7.23.2. Device Descriptor:

Device Descriptor:

VID (Vendor IDentifier) | 1155
LANGID_STRING (Language Identifier) | English(United States)
MANUFACTURER_STRING (Manufacturer Identifier) | STMicroelectronics
Device Descriptor FS:
PID (Product IDentifier) | 22336
PRODUCT_STRING (Product Identifier) | STM32 Virtual ComPort
CONFIGURATION_STRING (Configuration Identifier) | CDC Config
INTERFACE_STRING (Interface Identifier) | CDC Interface

* User modified value

## 8. System Configuration

### 8.1. GPIO configuration

IP | Pin | Signal | GPIO mode | GPIO pull/up pull down

Max
Speed

User Label

CAN | PD0 | CAN_RX | Alternate Function Push Pull | No pull-up and no pull-down | High *
| PD1 | CAN_TX | Alternate Function Push Pull | No pull-up and no pull-down | High *
DAC1 | PA4 | DAC1_OUT1 | Analog mode | No pull-up and no pull-down | n/a | AO0
| PA5 | DAC1_OUT2 | Analog mode | No pull-up and no pull-down | n/a | AO1
DAC2 | PA6 | DAC2_OUT1 | Analog mode | No pull-up and no pull-down | n/a | AO2
RCC | PC14- OSC32_IN | RCC_OSC32_IN | n/a | n/a | n/a
| PC15- OSC32_OU T | RCC_OSC32_O UT | n/a | n/a | n/a
PF0-OSC_IN RCC_OSC_IN | n/a | n/a | n/a
PF1-
OSC_OUT
| | RCC_OSC_OUT | n/a | n/a | n/a
SDADC1 | PB0 | SDADC1_AIN6P | Analog mode | No pull-up and no pull-down | n/a | AI0
| PB1 | SDADC1_AIN5P | Analog mode | No pull-up and no pull-down | n/a | AI1
| PB2 | SDADC1_AIN4P | Analog mode | No pull-up and no pull-down | n/a | AI2
| PE7 | SDADC1_AIN3P | Analog mode | No pull-up and no pull-down | n/a | AI3
| PE8 | SDADC1_AIN8P | Analog mode | No pull-up and no pull-down | n/a | AI4
| PE9 | SDADC1_AIN7P | Analog mode | No pull-up and no pull-down | n/a | AI5
| PE10 | SDADC1_AIN2P | Analog mode | No pull-up and no pull-down | n/a | AI6
| PE11 | SDADC1_AIN1P | Analog mode | No pull-up and no pull-down | n/a | AI7
| PE12 | SDADC1_AIN0P | Analog mode | No pull-up and no pull-down | n/a | AI8
SDADC2 | PE13 | SDADC2_AIN2P | Analog mode | No pull-up and no pull-down | n/a | AI9
| PE14 | SDADC2_AIN1P | Analog mode | No pull-up and no pull-down | n/a | AI10
| PE15 | SDADC2_AIN0P | Analog mode | No pull-up and no pull-down | n/a | AI11
SDADC3 | PB14 | SDADC3_AIN8P | Analog mode | No pull-up and no pull-down | n/a | DAI0P
| PB15 | SDADC3_AIN8M | Analog mode | No pull-up and no pull-down | n/a | DAI0M
| PD8 | SDADC3_AIN6P | Analog mode | No pull-up and no pull-down | n/a | DAI1P
| PD9 | SDADC3_AIN6M | Analog mode | No pull-up and no pull-down | n/a | DAI1M
| PD10 | SDADC3_AIN4P | Analog mode | No pull-up and no pull-down | n/a | DAI2P
| PD11 | SDADC3_AIN4M | Analog mode | No pull-up and no pull-down | n/a | DAI2M
| PD12 | SDADC3_AIN2P | Analog mode | No pull-up and no pull-down | n/a | DAI3P
| PD13 | SDADC3_AIN2M | Analog mode | No pull-up and no pull-down | n/a | DAI3M
| PD14 | SDADC3_AIN0P | Analog mode | No pull-up and no pull-down | n/a | DAI4P
| PD15 | SDADC3_AIN0M | Analog mode | No pull-up and no pull-down | n/a | DAI4M
SPI2 | PB10 | SPI2_SCK | Alternate Function Push Pull | No pull-up and no pull-down | High *

IP | Pin | Signal | GPIO mode | GPIO pull/up pull down | Max Speed | User Label
| PD3 | SPI2_MISO | Alternate Function Push Pull | Pull-down * | High *
| PD4 | SPI2_MOSI | Alternate Function Push Pull | No pull-up and no pull-down | High *
SYS | PA13 | SYS_JTMS-SWDIO | n/a | n/a | n/a
| PA14 | SYS_JTCK-SWCLK | n/a | n/a | n/a
| PB3 | SYS_JTDO-TRACESWO | n/a | n/a | n/a
TIM2 | PA0 | TIM2_CH1 | Alternate Function Push Pull | No pull-up and no pull-down | Low | PWM4
| PA1 | TIM2_CH2 | Alternate Function Push Pull | No pull-up and no pull-down | Low | PWM5
| PA9 | TIM2_CH3 | Alternate Function Push Pull | No pull-up and no pull-down | Low | PWM6
| PA10 | TIM2_CH4 | Alternate Function Push Pull | No pull-up and no pull-down | Low | PWM7
TIM3 | PC6 | TIM3_CH1 | Alternate Function Push Pull | No pull-up and no pull-down | Low | E2-
| PC7 | TIM3_CH2 | Alternate Function Push Pull | No pull-up and no pull-down | Low | E2+
TIM4 | PB6 | TIM4_CH1 | Alternate Function Push Pull | No pull-up and no pull-down | Low | E0-
| PB7 | TIM4_CH2 | Alternate Function Push Pull | No pull-up and no pull-down | Low | E0+
TIM5 | PC0 | TIM5_CH1 | Alternate Function Push Pull | No pull-up and no pull-down | Low | PWM0
| PC1 | TIM5_CH2 | Alternate Function Push Pull | No pull-up and no pull-down | Low | PWM1
| PC2 | TIM5_CH3 | Alternate Function Push Pull | No pull-up and no pull-down | Low | PWM2
| PC3 | TIM5_CH4 | Alternate Function Push Pull | No pull-up and no pull-down | Low | PWM3
TIM15 | PA2 | TIM15_CH1 | Alternate Function Push Pull | No pull-up and no pull-down | Low | IC2
| PA3 | TIM15_CH2 | Alternate Function Push Pull | No pull-up and no pull-down | Low | IC3
TIM16 | PB8 | TIM16_CH1 | Alternate Function Push Pull | No pull-up and no pull-down | Low | IC1
TIM17 | PB9 | TIM17_CH1 | Alternate Function Push Pull | No pull-up and no pull-down | Low | IC0
TIM19 | PC10 | TIM19_CH1 | Alternate Function Push Pull | No pull-up and no pull-down | Low | E1-
| PC11 | TIM19_CH2 | Alternate Function Push Pull | No pull-up and no pull-down | Low | E1+
USB | PA11 | USB_DM | Alternate Function Push Pull | No pull-up and no pull-down | High *
| PA12 | USB_DP | Alternate Function Push Pull | No pull-up and no pull-down | High *
GPIO | PE2 | GPIO_Input | Input mode | Pull-down * | n/a | DI0
| PE3 | GPIO_Input | Input mode | Pull-down * | n/a | DI1
| PE4 | GPIO_Input | Input mode | Pull-down * | n/a | DI2
| PE5 | GPIO_Input | Input mode | Pull-down * | n/a | DI3
| PE6 | GPIO_Input | Input mode | Pull-down * | n/a | DI4
| PC13 | GPIO_Input | Input mode | Pull-down * | n/a | DI5
| PF9 | GPIO_Input | Input mode | Pull-down * | n/a | DI8
| PF10 | GPIO_Input | Input mode | Pull-down * | n/a | DI9
| PA7 | GPIO_Output | Output Push Pull | No pull-up and no pull-down | Low | LED_USB
| PC4 | GPIO_Output | Output Push Pull | No pull-up and no pull-down | Low | LED_CAN
| PC5 | GPIO_Output | Output Push Pull | No pull-up and no pull-down | Low | LED_ERROR

IP | Pin | Signal | GPIO mode | GPIO pull/up pull down | Max Speed | User Label
| PD5 | GPIO_Output | Output Push Pull | No pull-up and no pull-down | Low | CS0
| PD6 | GPIO_Output | Output Push Pull | No pull-up and no pull-down | Low | CS1
| PD7 | GPIO_Output | Output Push Pull | No pull-up and no pull-down | Low | CS2
| PB4 | GPIO_Input | Input mode | No pull-up and no pull-down | n/a | DI7
| PB5 | GPIO_Input | Input mode | No pull-up and no pull-down | n/a | DI6

### 8.2. DMA configuration

DMA request | Stream | Direction | Priority
TIM17_CH1/UP | DMA1_Channel1 | Peripheral To Memory | Low
TIM16_CH1/UP | DMA1_Channel3 | Peripheral To Memory | Low
SDADC1 | DMA2_Channel3 | Peripheral To Memory | Low
SDADC2 | DMA2_Channel4 | Peripheral To Memory | Low
SDADC3 | DMA2_Channel5 | Peripheral To Memory | Low
TIM15_CH1/UP/TRIG/COM | DMA1_Channel5 | Peripheral To Memory | Low

TIM17_CH1/UP: DMA1_Channel1 DMA request Settings:

Mode: | Circular *
Peripheral Increment: | Disable
Memory Increment: | Enable *
Peripheral Data Width: | Half Word
Memory Data Width: | Half Word

TIM16_CH1/UP: DMA1_Channel3 DMA request Settings:

Mode: | Circular *
Peripheral Increment: | Disable
Memory Increment: | Enable *
Peripheral Data Width: | Half Word
Memory Data Width: | Half Word

SDADC1: DMA2_Channel3 DMA request Settings:

Mode: | Circular *
Peripheral Increment: | Disable
Memory Increment: | Enable *
Peripheral Data Width: | Half Word
Memory Data Width: | Half Word

SDADC2: DMA2_Channel4 DMA request Settings:

Mode: | Circular *
Peripheral Increment: | Disable

Memory Increment: | Enable *
Peripheral Data Width: | Half Word
Memory Data Width: | Half Word

SDADC3: DMA2_Channel5 DMA request Settings:

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

TIM15_CH1/UP/TRIG/COM: DMA1_Channel5 DMA request Settings:

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

### 8.3. NVIC configuration

8.3.1. NVIC
Interrupt Table | Enable | Preenmption Priority | SubPriority
Non maskable interrupt | true | 0 | 0
Hard fault interrupt | true | 0 | 0
Memory management fault | true | 0 | 0
Prefetch fault, memory access fault | true | 0 | 0
Undefined instruction or illegal state | true | 0 | 0
System service call via SWI instruction | true | 0 | 0
Debug monitor | true | 0 | 0
Pendable request for system service | true | 0 | 0
System tick timer | true | 0 | 0
DMA1 channel1 global interrupt | true | 0 | 0
DMA1 channel3 global interrupt | true | 0 | 0
DMA1 channel5 global interrupt | true | 0 | 0
CAN RX0 interrupt | true | 0 | 0
TIM15 global interrupt | true | 0 | 0
RTC alarms A and B interrupt through EXTI line 17 | true | 0 | 0
DMA2 channel3 global interrupt | true | 0 | 0
DMA2 channel4 global interrupt | true | 0 | 0
DMA2 channel5 global interrupt | true | 0 | 0
USB low priority global interrupt | true | 0 | 0
PVD interrupt through EXTI line16 | unused
Flash global interrupt | unused
RCC global interrupt | unused
CAN TX interrupt | unused
CAN RX1 interrupt | unused
CAN SCE interrupt | unused
TIM16 global interrupt | unused
TIM17 global interrupt | unused
TIM18 global interrupt and DAC2 underrun error interrupt | unused
TIM2 global interrupt | unused
TIM3 global interrupt | unused
TIM4 global interrupt | unused
SPI2 global interrupt | unused
TIM12 global interrupt | unused
TIM13 global interrupt | unused
TIM5 global interrupt | unused
TIM6 global interrupt and DAC1 underrun error interrupts | unused

Interrupt Table | Enable | Preenmption Priority | SubPriority
SDADC1 global interrupt | unused
SDADC2 global interrupt | unused
SDADC3 global interrupt | unused
USB high priority global interrupt | unused
TIM19 global interrupt | unused
Floating point unit interrupt | unused
8.3.2. NVIC Code generation
Enabled interrupt Table | Select for init sequence ordering | Generate IRQ handler | Call HAL handler
Non maskable interrupt | false | true | false
Hard fault interrupt | false | true | false
Memory management fault | false | true | false
Prefetch fault, memory access fault | false | true | false
Undefined instruction or illegal state | false | true | false
System service call via SWI instruction | false | true | false
Debug monitor | false | true | false
Pendable request for system service | false | true | false
System tick timer | false | true | true
DMA1 channel1 global interrupt | false | true | true
DMA1 channel3 global interrupt | false | true | true
DMA1 channel5 global interrupt | false | true | true
CAN RX0 interrupt | false | true | true
TIM15 global interrupt | false | true | true
RTC alarms A and B interrupt through EXTI line 17 | false | true | true
DMA2 channel3 global interrupt | false | true | true
DMA2 channel4 global interrupt | false | true | true
DMA2 channel5 global interrupt | false | true | true
USB low priority global interrupt | false | true | true

* User modified value

## 9. System Views

9.1. Category view
9.1.1. Current

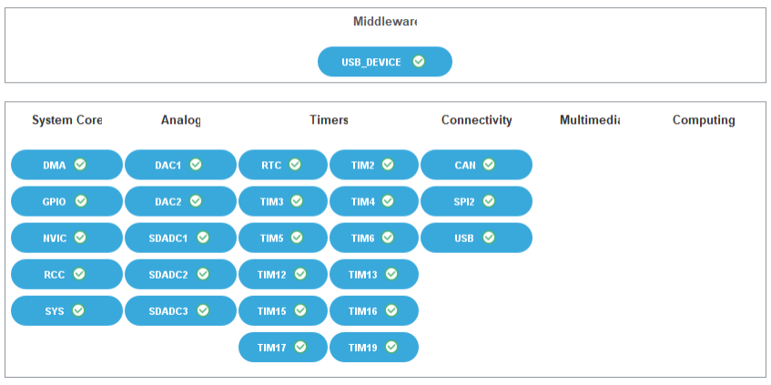
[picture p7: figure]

## 10. Docs & Resources

Type | Link
Presentations | https://www.st.com/resource/en/product_presentation/stm32-stm8_embedded_software_solutions.pdf
Presentations | https://www.st.com/resource/en/product_presentation/stm32_eval-tools_portfolio.pdf
Presentations | https://www.st.com/resource/en/product_presentation/stm32_stm8_functi onal-safety-packages.pdf
Presentations | https://www.st.com/resource/en/product_presentation/stm32-stm8_software_development_tools.pdf
Training Material | https://www.st.com/resource/en/sales_guide/sg_sc2155.pdf
Brochures | https://www.st.com/resource/en/brochure/brstm32f3.pdf
Flyers | https://www.st.com/resource/en/flyer/flnucleolrwan.pdf
Flyers | https://www.st.com/resource/en/flyer/flstm32nucleo.pdf
Flyers | https://www.st.com/resource/en/flyer/flstmcsuite.pdf
Flyers | https://www.st.com/resource/en/flyer/flpowerstbd.pdf
Flyers | https://www.st.com/resource/en/flyer/fldpstpfc11120.pdf
Product Certifications | https://www.st.com/resource/en/certification_document/stm32_authentication_can.pdf
Application Notes | https://www.st.com/resource/en/application_note/an1181-electrostatic-discharge-sensitivity-measurement-stmicroelectronics.pdf
Application Notes | https://www.st.com/resource/en/application_note/an1709-emc-design-guide-for-stm8-stm32-and-legacy-mcus-stmicroelectronics.pdf
Application Notes | https://www.st.com/resource/en/application_note/an2548-using-the-stm32f0f1f3gxlx-series-dma-controller-stmicroelectronics.pdf
Application Notes | https://www.st.com/resource/en/application_note/an2606-stm32-microcontroller-system-memory-boot-mode-stmicroelectronics.pdf
Application Notes | https://www.st.com/resource/en/application_note/an2639-soldering-recommendations-and-package-information-for-leadfree-ecopack-mcus-and-mpus-stmicroelectronics.pdf
Application Notes | https://www.st.com/resource/en/application_note/an2834-how-to-get-the-

| best-adc-accuracy-in-stm32-microcontrollers-stmicroelectronics.pdf
Application Notes | https://www.st.com/resource/en/application_note/an2945-stm8s-and-stm32-mcus-a-consistent-832bit-product-line-for-painless-migration-stmicroelectronics.pdf
Application Notes | https://www.st.com/resource/en/application_note/an3070-managing-the-driver-enable-signal-for-rs485-and-iolink-communications-with-the-stm32s-usart-stmicroelectronics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
Application Notes | https://www.st.com/resource/en/application_note/an3126-audio-and-waveform-generation-using-the-dac-in-stm32-products-stmicroelectronics.pdf
Application Notes | https://www.st.com/resource/en/application_note/an3155-usart-protocol-used-in-the-stm32-bootloader-stmicroelectronics.pdf
Application Notes | https://www.st.com/resource/en/application_note/an3156-usb-dfu-protocol-used-in-the-stm32-bootloader-stmicroelectronics.pdf
Application Notes | https://www.st.com/resource/en/application_note/an3236-increase-the-number-of-touchkeys-for-touch-sensing-applications-on-mcus-stmicroelectronics.pdf
Application Notes | https://www.st.com/resource/en/application_note/an3371-using-the-hardware-realtime-clock-rtc-in-stm32-f0-f2-f3-f4-and-l1-series-of-mcus-stmicroelectronics.pdf
Application Notes | https://www.st.com/resource/en/application_note/an3960-esd-considerations-for-touch-sensing-applications-on-mcus-stmicroelectronics.pdf
Application Notes | https://www.st.com/resource/en/application_note/an4013-stm32-crossseries-timer-overview-stmicroelectronics.pdf
Application Notes | https://www.st.com/resource/en/application_note/an4045-stm32f3-series-inapplication-programming-iap-using-the-usart-stmicroelectronics.pdf
Application Notes | https://www.st.com/resource/en/application_note/an4099-implementation-of-transmitters-and-receivers-for-infrared-remote-control-protocols-with-mcus-of-the-stm32f0-an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
Application Notes | https://www.st.com/resource/en/application_note/an4206-getting-started-with-stm32f3-series-hardware-development-stmicroelectronics.pdf
Application Notes | https://www.st.com/resource/en/application_note/an4207-getting-started-

| with-stm32f3738xxx-sdadc-sigmadelta-adc-stmicroelectronics.pdf
Application Notes | https://www.st.com/resource/en/application_note/an4221-i2c-protocol-used-in-the-stm32-bootloader-stmicroelectronics.pdf
Application Notes | https://www.st.com/resource/en/application_note/an4228-migrating-from-stm32f1-series-to-stm32f3-series-microcontrollers-stmicroelectronics.pdf
Application Notes | https://www.st.com/resource/en/application_note/an4229-how-to-implement-a-vocoder-solution-using-stm32-microcontrollers-stmicroelectronics.pdf
Application Notes | https://www.st.com/resource/en/application_note/an4232-getting-started-with-analog-comparators-for-stm32f3-series-and-stm32g4-series-devices-stmicroelectronics.pdf
Application Notes | https://www.st.com/resource/en/application_note/an4277-using-stm32-device-pwm-shutdown-features-for-motor-control-and-digital-power-conversion-stmicroelectronics.pdf
Application Notes | https://www.st.com/resource/en/application_note/an4299-improve-conducted-noise-robustness-for-touch-sensing-applications-on-mcus-stmicroelectronics.pdf
Application Notes | https://www.st.com/resource/en/application_note/an4310-sampling-capacitor-selection-guide-for-touch-sensing-applications-on-mcus-stmicroelectronics.pdf
Application Notes | https://www.st.com/resource/en/application_note/an4312-design-with-surface-sensors-for-touch-sensing-applications-on-mcus-stmicroelectronics.pdf
Application Notes | https://www.st.com/resource/en/application_note/an4316-tuning-a-touch-sensing-application-on-mcus-stmicroelectronics.pdf
Application Notes | https://www.st.com/resource/en/application_note/an4538-power-consumption-optimization-with-stm32f3xx-microcontrollers-stmicroelectronics.pdf
Application Notes | https://www.st.com/resource/en/application_note/an4550-getting-started-with-stm32f373378ccrcvc-sdadc-sigmadelta-adc--stmicroelectronics.pdf
Application Notes | https://www.st.com/resource/en/application_note/an4566-extending-the-dac-performance-of-stm32-microcontrollers-stmicroelectronics.pdf
Application Notes | https://www.st.com/resource/en/application_note/an4651-stm32f3-series-

| peripheral-interconnect-matrix-stmicroelectronics.pdf
Application Notes | https://www.st.com/resource/en/application_note/an4655-virtually-increasing-the-number-of-serial-communication-peripherals-in-stm32-applications-stmicroelectronics.p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
Application Notes | https://www.st.com/resource/en/application_note/an4734-stm32cube-firmware-examples-for-stm32f3-series-stmicroelectronics.pdf
Application Notes | https://www.st.com/resource/en/application_note/an4750-handling-of-soft-errors-in-stm32-applications-stmicroelectronics.pdf
Application Notes | https://www.st.com/resource/en/application_note/an4759-using-the-hardware-realtime-clock-rtc-and-the-tamper-management-unit-tamp-with-stm32-microcontrollers-stmicroe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
Application Notes | https://www.st.com/resource/en/application_note/an4776-generalpurpose-timer-cookbook-for-stm32-microcontrollers-stmicroelectronics.pdf
Application Notes | https://www.st.com/resource/en/application_note/an4803-highspeed-si-simulations-using-ibis-and-boardlevel-simulations-using-hyperlynx-si-on-stm32-mcus-and-mpus-stmic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
Application Notes | https://www.st.com/resource/en/application_note/an4838-managing-memory-protection-unit-in-stm32-mcus-stmicroelectronics.pdf
Application Notes | https://www.st.com/resource/en/application_note/an4879-usb-hardware-and-pcb-guidelines-using-stm32-mcus-stmicroelectronics.pdf
Application Notes | https://www.st.com/resource/en/application_note/an4908-stm32-usart-automatic-baud-rate-detection-stmicroelectronics.pdf
Application Notes | https://www.st.com/resource/en/application_note/an4989-stm32-microcontroller-debug-toolbox-stmicroelectronics.pdf
Application Notes | https://www.st.com/resource/en/application_note/an4991-how-to-wake-up-an-stm32xx-series-microcontroller-from-lowpower-mode-with-the-usart-or-the-lpuart-stmicroelectr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
Application Notes | https://www.st.com/resource/en/application_note/an5027-interfacing-pdm-digital-microphones-using-stm32-mcus-and-mpus-stmicroelectronics.pdf
Application Notes | https://www.st.com/resource/en/application_note/an5036-thermal-management-guidelines-for-stm32-applications-stmicroelectronics.pdf
Application Notes | https://www.st.com/resource/en/application_note/an5105-getting-started- with-touch-sensing-control-on-stm32-microcontrollers-

| stmicroelectronics.pdf
Application Notes | https://www.st.com/resource/en/application_note/an5156-introduction-to-stm32-microcontrollers-security-stmicroelectronics.pdf
Application Notes | https://www.st.com/resource/en/application_note/an5225-usb-typec-power-delivery-using-stm32-mcus-and-mpus-stmicroelectronics.pdf
Application Notes | https://www.st.com/resource/en/application_note/an5310-guideline-for-using-analog-features-of-stm32g4-series-versus-stm32f3-series-devices-stmicroelectronics.pdf
Application Notes | https://www.st.com/resource/en/application_note/an5543-enhanced-methods-to-handle-spi-communication-on-stm32-devices-stmicroelectronics.pdf
Application Notes | https://www.st.com/resource/en/application_note/an4899-stm32-microcontroller-gpio-hardware-settings-and-lowpower-consumption-stmicroelectronics.pdf
Application Notes for related Tools & Software | https://www.st.com/resource/en/application_note/an1202_freertos_guide-freertos-guide-stmicroelectronics.pdf
Application Notes for related Tools & Software | https://www.st.com/resource/en/application_note/an1602_semihosting_in_truestudio-how-to-do-semihosting-in-truestudio-stmicroelectronics.pdf
Application Notes for related Tools & Software | https://www.st.com/resource/en/application_note/an1801_stm32cubeprogrammer_in_truestudio-installing-stm32cubeprogrammer-in-truestudio-stmicroelectronics.pdf
Application Notes for related Tools & Software | https://www.st.com/resource/en/application_note/atollic_editing_keyboard_shortcuts-atollic-editing-keyboard-shortcuts-stmicroelectronics.pdf
Application Notes for related Tools & Software | https://www.st.com/resource/en/application_note/iar_to_atollic_truestudio_migration_guide-truestudio-for-arm-migration-guide-iar-embedded-workbench-to-truestudio-stm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
Application Notes for related Tools & Software | https://www.st.com/resource/en/application_note/stm32cubemx_installation_in_truestudio-stm32cubemx-installation-in-truestudio-stmicroelectronics.pdf

Application Notes
for related Tools

https://www.st.com/resource/en/application_note/an2656-stm32f10xxxlcd-glass-driver-firmware-stmicroelectronics.pdf

& Software
Application Notes for related Tools & Software | https://www.st.com/resource/en/application_note/an3078-stm32-inapplication-programming-over-the-ic-bus-stmicroelectronics.pdf
Application Notes for related Tools & Software | https://www.st.com/resource/en/application_note/an3116-stm32s-adc-modes-and-their-applications-stmicroelectronics.pdf
Application Notes for related Tools & Software | https://www.st.com/resource/en/application_note/an3174-implementing-receivers-for-infrared-remote-control-protocols-using-stm32f10xxx-microcontrollers-stmicroelectro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
Application Notes for related Tools & Software | https://www.st.com/resource/en/application_note/an3307-guidelines-for-obtaining-iec-60335-class-b-certification-for-any-stm32-application-stmicroelectronics.pdf
Application Notes for related Tools & Software | https://www.st.com/resource/en/application_note/an4044-floating-point-unit-demonstration-on-stm32-microcontrollers-stmicroelectronics.pdf
Application Notes for related Tools & Software | https://www.st.com/resource/en/application_note/an4045-stm32f3-series-inapplication-programming-iap-using-the-usart-stmicroelectronics.pdf
Application Notes for related Tools & Software | https://www.st.com/resource/en/application_note/an4056-eeprom-emulation-in-stm32f30xstm32f31xstm32f37xstm32f38x-microcontrollers-stmicroelectronics.pdf
Application Notes for related Tools & Software | https://www.st.com/resource/en/application_note/an4132-clock-configuration-tool-for-stm32f37xstm32f38x--microcontrollers-stmicroelectronics.pdf
Application Notes for related Tools & Software | https://www.st.com/resource/en/application_note/an4157-stm32f3discovery-peripheral-firmware-examples-stmicroelectronics.pdf
Application Notes for related Tools & Software | https://www.st.com/resource/en/application_note/an4187-using-the-crc-peripheral-in-the-stm32-family-stmicroelectronics.pdf
Application Notes for related Tools & Software | https://www.st.com/resource/en/application_note/an4235-i2c-timing-configuration-tool-for-stm32f3xxxx-and-stm32f0xxxx-microcontrollers-stmicroelectronics.pdf

Application Notes for related Tools & Software | https://www.st.com/resource/en/application_note/an4323-getting-started-with-stemwin-library-stmicroelectronics.pdf
Application Notes for related Tools & Software | https://www.st.com/resource/en/application_note/an4435-guidelines-for-obtaining-ulcsaiec-607301603351-class-b-certification-in-any-stm32-application-stmicroelectroni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
Application Notes for related Tools & Software | https://www.st.com/resource/en/application_note/an4449-buckboost-converter-using-the-stm32f334-discovery-kit-stmicroelectronics.pdf
Application Notes for related Tools & Software | https://www.st.com/resource/en/application_note/an4499-stm32--nrf51822-bluetooth-low-energy-system-solution-stmicroelectronics.pdf
Application Notes for related Tools & Software | https://www.st.com/resource/en/application_note/an4502-stm32-smbuspmbus-embedded-software-expansion-for-stm32cube-stmicroelectronics.pdf
Application Notes for related Tools & Software | https://www.st.com/resource/en/application_note/an4507-pwm-resolution-enhancement-through-a-dithering-technique-for-stm32-advancedconfiguration-generalpurpose-and-li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
Application Notes for related Tools & Software | https://www.st.com/resource/en/application_note/an4657-stm32-inapplication-programming-iap-using-the-usart-stmicroelectronics.pdf
Application Notes for related Tools & Software | https://www.st.com/resource/en/application_note/an4734-stm32cube-firmware-examples-for-stm32f3-series-stmicroelectronics.pdf
Application Notes for related Tools & Software | https://www.st.com/resource/en/application_note/an4759-using-the-hardware-realtime-clock-rtc-and-the-tamper-management-unit-tamp-with-stm32-microcontrollers-stmicroe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
Application Notes for related Tools & Software | https://www.st.com/resource/en/application_note/an4834-implementation-of-transmitters-and-receivers-for-infrared-remote-control-protocols-with-stm32cube-stmicroelect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
Application Notes for related Tools & Software | https://www.st.com/resource/en/application_note/an4841-digital-signal-processing-for-stm32-microcontrollers-using-cmsis-stmicroelectronics.pdf

Application Notes for related Tools & Software | https://www.st.com/resource/en/application_note/an4885-high-brightness-led-dimming-using-the-stm32f334-discovery-kit-stmicroelectronics.pdf
Application Notes for related Tools & Software | https://www.st.com/resource/en/application_note/an5054-secure-programming-using-stm32cubeprogrammer-stmicroelectronics.pdf
Application Notes for related Tools & Software | https://www.st.com/resource/en/application_note/an5360-getting-started-with-projects-based-on-the-stm32mp1-series-in-stm32cubeide-stmicroelectronics.pdf
Application Notes for related Tools & Software | https://www.st.com/resource/en/application_note/an5361-getting-started-with-projects-based-on-dualcore-stm32h7-microcontrollers-in-stm32cubeide-stmicroelectronics.pd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
Application Notes for related Tools & Software | https://www.st.com/resource/en/application_note/an5394-getting-started-with-projects-based-on-the-stm32l5-series-in-stm32cubeide-stmicroelectronics.pdf
Application Notes for related Tools & Software | https://www.st.com/resource/en/application_note/an5418-how-to-build-a-simple-usbpd-sink-application-with-stm32cubemx-stmicroelectronics.pdf
Application Notes for related Tools & Software | https://www.st.com/resource/en/application_note/an5426-migrating-graphics-middleware-projects-from-stm32cubemx-540-to-stm32cubemx-550-stmicroelectronics.pdf
Application Notes for related Tools & Software | https://www.st.com/resource/en/application_note/an5464-position-control-of-a-threephase-permanent-magnet-motor-using-xcubemcsdk-or-xcubemcsdkful-stmicroelectronics.p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
Application Notes for related Tools & Software | https://www.st.com/resource/en/application_note/an5564-getting-started-with-projects-based-on-dualcore-stm32wl-microcontrollers-in-stm32cubeide-stmicroelectronics.pd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
Application Notes for related Tools & Software | https://www.st.com/resource/en/application_note/an5698-adapting-the-xcubestl-functional-safety-package-for-stm32-iec-61508-compliant-to-other-safety-standards-stmicr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
Application Notes for related Tools & Software | https://www.st.com/resource/en/application_note/an5731-stm32cubemx-and-stm32cubeide-threadsafe-solution-stmicroelectronics.pdf
Errata Sheets | https://www.st.com/resource/en/errata_sheet/es0189-stm32f373xx-

| device-limitations-stmicroelectronics.pdf
Datasheet | https://www.st.com/resource/en/datasheet/dm00046749.pdf
Programming Manuals | https://www.st.com/resource/en/programming_manual/pm0214-stm32-cortexm4-mcus-and-mpus-programming-manual-stmicroelectronics.pdf
Reference Manuals | https://www.st.com/resource/en/reference_manual/rm0313-stm32f37xxx-advanced-armbased-32bit-mcus-stmicroelectronics.pdf
Technical Notes & Articles | https://www.st.com/resource/en/technical_note/tn1163-description-of-wlcsp-for-microcontrollers-and-recommendations-for-its-use-stmicroelectronics.pdf
Technical Notes & Articles | https://www.st.com/resource/en/technical_note/tn1204-tape-and-reel-shipping-media-for-stm32-microcontrollers-in-bga-packages-stmicroelectronics.pdf
Technical Notes & Articles | https://www.st.com/resource/en/technical_note/tn1205-tape-and-reel-shipping-media-for-stm8-and-stm32-microcontrollers-in-fpn-packages-stmicroelectronics.pdf
Technical Notes & Articles | https://www.st.com/resource/en/technical_note/tn1206-tape-and-reel-shipping-media-for-stm8-and-stm32-microcontrollers-in-qfp-packages-stmicroelectronics.pdf
Technical Notes & Articles | https://www.st.com/resource/en/technical_note/tn1207-tape-and-reel-shipping-media-for-stm8-and-stm32-microcontrollers-in-so-packages-stmicroelectronics.pdf
Technical Notes & Articles | https://www.st.com/resource/en/technical_note/tn1208-tape-and-reel-shipping-media-for-stm8-and-stm32-microcontrollers-in-tssop-and-ssop-packages-stmicroelectronics.p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

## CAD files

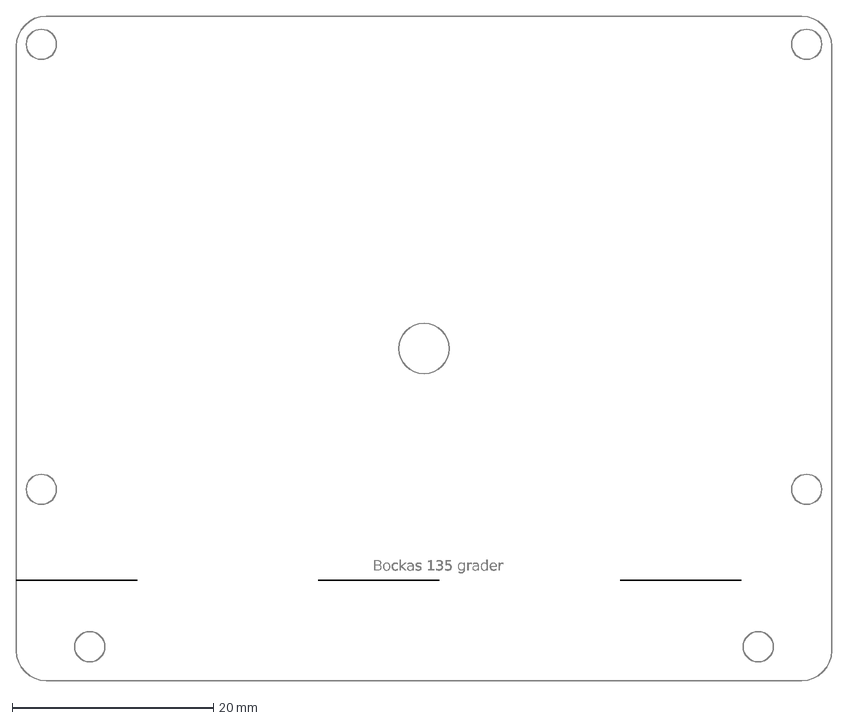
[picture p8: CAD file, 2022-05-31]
Cad/LCD holder.dxf
Bockas 135 grader

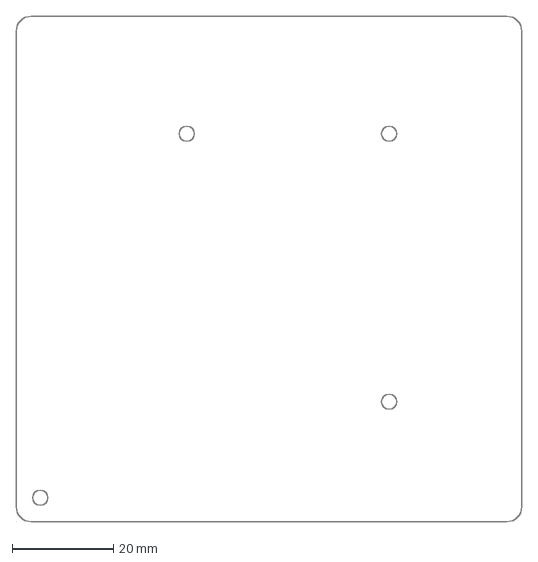
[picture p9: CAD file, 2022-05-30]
Cad/Bottom.dxf
100.0 x 100.0 mm

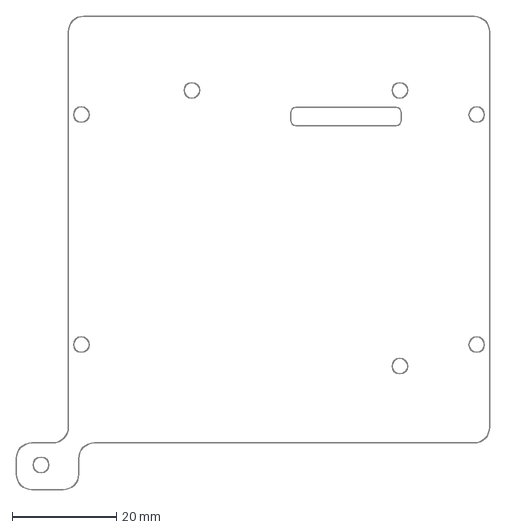
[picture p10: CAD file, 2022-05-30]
Cad/Top.dxf
91.0 x 91.0 mm

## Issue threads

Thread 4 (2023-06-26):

official gerbers?

rusefillc, 2023-06-26:
Are gerber files not universal enough for this repo to have official artifacts?

Also there is that one single amazingly cheap fabrication shop with PCB assembly files, an official BOM + placement file would allow for simpler fabrication.

DanielMartensson, 2023-06-26:
I don't know what you mean. I have been using gerber files for JLCPCB.

rusefillc, 2023-06-26:
DanielMartensson says 'download kicad, click "export", make sure not to mess up, export gerbers, make sure not to forget to export drill file separately"

https://github.com/rusefi/hw_microRusEfi/tree/master/gerbers/R0.6.0 is an example of an alternative approach which would be "oh you want to just USE our hardware? here are gerbers no need to leard kicad"

I suggest a usability improvement for people who just want hardware as is

DanielMartensson, 2023-06-26:
Well, to build this project, you need to know what you are doing. This is not a beginner example.

rusefillc, 2023-06-26:
@DanielMartensson only people capable of kicad are capable to solder? What about Altium professionals, would they all NOT be able to solder?

Actually here is another idea: humans should not be soldering this project. Humans should have a choice of using JLCPCB assembly services and let machines solder components on PCBs.

DanielMartensson, 2023-06-26:
I don't know what I will answer to that.

Closed 2023-06-27.

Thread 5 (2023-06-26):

official binaries?

rusefillc, 2023-06-26:
why torture users with a UI IDE? since this is DONE maybe help potential users with official binaries?

in six years from now it would be much easier to have binaries instead of trying to find a matching version of the IDE

DanielMartensson, 2023-06-26:
What's wrong with STM32CubeIDE?

rusefillc, 2023-06-26:
Nothing is wrong with STM32CubeIDE today.

I am speaking about
* usability for end users
* long term risk

in 6 years from today there is a good chance that newer STM32CubeIDE would not open current project. in 6 years there is a good chance that older version would be either hard to get or would refuse to install along side current version. C'mon, compiler warning/error behavior for corner cases changes every couple of years, Windows vs Linux versions of same compiler are themselves compiled with different flags! In my opinion a better way to open source is a combination of source code AND official binaries.

DanielMartensson, 2023-06-26:
ST will always provide support to migrate old projects to new projects.

But I'm posting the source code?

rusefillc, 2023-06-26:
@DanielMartensson you are placing too much faith in ST. They are humans, they have defects and sometimes they do not fix those defect for years.

DanielMartensson, 2023-06-26:
@rusefillc  Yes I know. But at least they trying to build tools that are very easy to use. Also ST mcu are very cheap.

Closed 2023-06-27.

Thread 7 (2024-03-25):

STM32 reference direction

MrHorizonPy, 2024-03-25:
Can you tell me if the controller is correctly installed on the board? After loading the .ico file, only the backlight comes on at the display, the LEDs don't light up, but it seems that the loading went correctly. I attach some photos.
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

Thanks you.

DanielMartensson, 2024-03-26:
Does your LSE working ?

MrHorizonPy, 2024-03-26:
Yes it seems to be working, this is another error it gives me:
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

DanielMartensson, 2024-03-26:
@MrHorizonPy  so it stops at HAL_init()?

MrHorizonPy, 2024-03-26:
yes

DanielMartensson, 2024-03-26:
> yes

@MrHorizonPy  at what line? It seems you're having a software issue rather than hardware issue.

Can you investigate more ? I can help.

MrHorizonPy, 2024-03-26:
What do you need to know?

DanielMartensson, 2024-03-26:
> What do you need to know?

@MrHorizonPy  everything. What is the code that cause issues. What's the error message?

MrHorizonPy, 2024-03-26:
GNU gdb (GNU Tools for STM32 11.3.rel1.20230912-1600) 12.1.90.20220802-git
Copyright (C) 2022 Free Software Foundation, Inc.
License GPLv3+: GNU GPL version 3 or later <http://gnu.org/licenses/gpl.html>
This is free software: you are free to change and redistribute it.
There is NO WARRANTY, to the extent permitted by law.
Type "show copying" and "show warranty" for details.
This GDB was configured as "--host=x86_64-w64-mingw32 --target=arm-none-eabi".
Type "show configuration" for configuration details.
For bug reporting instructions, please see:
<https://www.gnu.org/software/gdb/bugs/>.
Find the GDB manual and other documentation resources online at:
    <http://www.gnu.org/software/gdb/documentation/>.

For help, type "help".
Type "apropos word" to search for commands related to "word".

set *(int *)0xE000EDFC=*(int *)0xE000EDFC|0x7F0

Temporary breakpoint 1, main () at ../Core/Src/main.c:125
125	  HAL_Init();

MrHorizonPy, 2024-03-26:
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

MrHorizonPy, 2024-03-26:
This is the error it gives me

DanielMartensson, 2024-03-26:
@MrHorizonPy  Can you step inside the HAL_Init(); function? Use the "step-inside" button
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

MrHorizonPy, 2024-03-27:
Hi @DanielMartensson
 I tried as you told me but it is since yesterday stuck in running and not going on

DanielMartensson, 2024-03-27:
@MrHorizonPy

So at which line does it stop? Inside HAL_init() function.

MrHorizonPy, 2024-03-27:
yes

DanielMartensson, 2024-03-27:
> yes

@MrHorizonPy  and? More information...which code line ?

MrHorizonPy, 2024-03-27:
the error is always the same, I am probably doing something wrong or I don't have some library installed. Mica you can provide me with some more information?

DanielMartensson, 2024-03-27:
> the error is always the same, I am probably doing something wrong or I don't have some library installed. Mica you can provide me with some more information?

 @MrHorizonPy It seems that you having more errors?

Yes, you're probably flashing it wrong.

Post the total build output and debug output

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

MrHorizonPy, 2024-03-28:
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
Hi @DanielMartensson , I am sending you the photo with the error message. It`s still the same as the previous one, once I baipass the error as you told me the test stays stuck running without ever becoming complete.
I am sending you the full text of the debug console:
GNU gdb (GNU Tools for STM32 12.3.rel1.20240306-1730) 13.2.90.20230627-git
Copyright (C) 2023 Free Software Foundation, Inc.
License GPLv3+: GNU GPL version 3 or later <http://gnu.org/licenses/gpl.html>
This is free software: you are free to change and redistribute it.
There is NO WARRANTY, to the extent permitted by law.
Type "show copying" and "show warranty" for details.
This GDB was configured as "--host=x86_64-w64-mingw32 --target=arm-none-eabi".
Type "show configuration" for configuration details.
For bug reporting instructions, please see:
<https://www.gnu.org/software/gdb/bugs/>.
Find the GDB manual and other documentation resources online at:
    <http://www.gnu.org/software/gdb/documentation/>.

For help, type "help".
Type "apropos word" to search for commands related to "word".

set *(int *)0xE000EDFC=*(int *)0xE000EDFC|0x7F0

Temporary breakpoint 1, main () at ../Core/Src/main.c:124
124	  HAL_Init();

DanielMartensson, 2024-03-28:
@MrHorizonPy

Have you created the temporary breakpoint in the code?

So you cannot step inside the HAL_init(); function during debug? Once you came to HAL_init(); your debugging freeze or what?

MrHorizonPy, 2024-03-28:
Hi,
Yes I created a temporary breakpoint, debugging continues but remains running without ever completing or giving any other errors.
How do I disable the LSE clock?
The soldering seems to be all correct I also measured the voltages based on the PCB you drew. My only doubt at first was about the direction of the STM32 as it has 2 reference dots

DanielMartensson, 2024-03-29:
> Hi, Yes I created a temporary breakpoint, debugging continues but remains running without ever completing or giving any other errors. How do I disable the LSE clock? The soldering seems to be all correct I also measured the voltages based on the PCB you drew. My only doubt at first was about the direction of the STM32 as it has 2 reference dots

Sorry for late response. I'm at holiday in the mountains and driving snowmobile.

So if your basic project works fine without errors, then it seems that there is something with the clocks, I guess.
Even if your solderings are correct, it might have some flux left or contamination.

You can disable the LSE clock at the RCC in STM32CubeIDE. Just set it as disable.

I'm sure that your PCB board will work. We need just to find a solution.

Closed 2024-04-03.

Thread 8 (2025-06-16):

UART?

samuk, 2025-06-16:
I'm interested in learning a bit about Modbus. I think I'd need a [RS485 adapter](https://www.olimex.com/Products/Modules/Interface/MOD-RS485-ISO/open-source-hardware) to do that. Looking at the adapter schematic it seems I'd need TX & RX and two additional IO.

Looking at [your schematic](https://github.com/user-attachments/files/20763834/output.pdf) It's not obvious to me which if any are UART TX/RX pins?

Is it possible to do Modbus with your board?

samuk, 2025-06-18:
Thanks, USB wouldn't fit my use case.

I was hoping to use these as remote nodes in a modbus network for data collection, I think I've identified an [alternate board ](https://www.olimex.com/Products/Duino/STM32/OLIMEXINO-STM32F3/open-source-hardware) that better fits this use case.

DanielMartensson, 2025-06-19:
> Thanks, USB wouldn't fit my use case.
>
> I was hoping to use these as remote nodes in a modbus network for data collection, I think I've identified an [alternate board ](https://www.olimex.com/Products/Duino/STM32/OLIMEXINO-STM32F3/open-source-hardware) that better fits this use case.

@samuk

You can have Modbus on CAN bus as well.

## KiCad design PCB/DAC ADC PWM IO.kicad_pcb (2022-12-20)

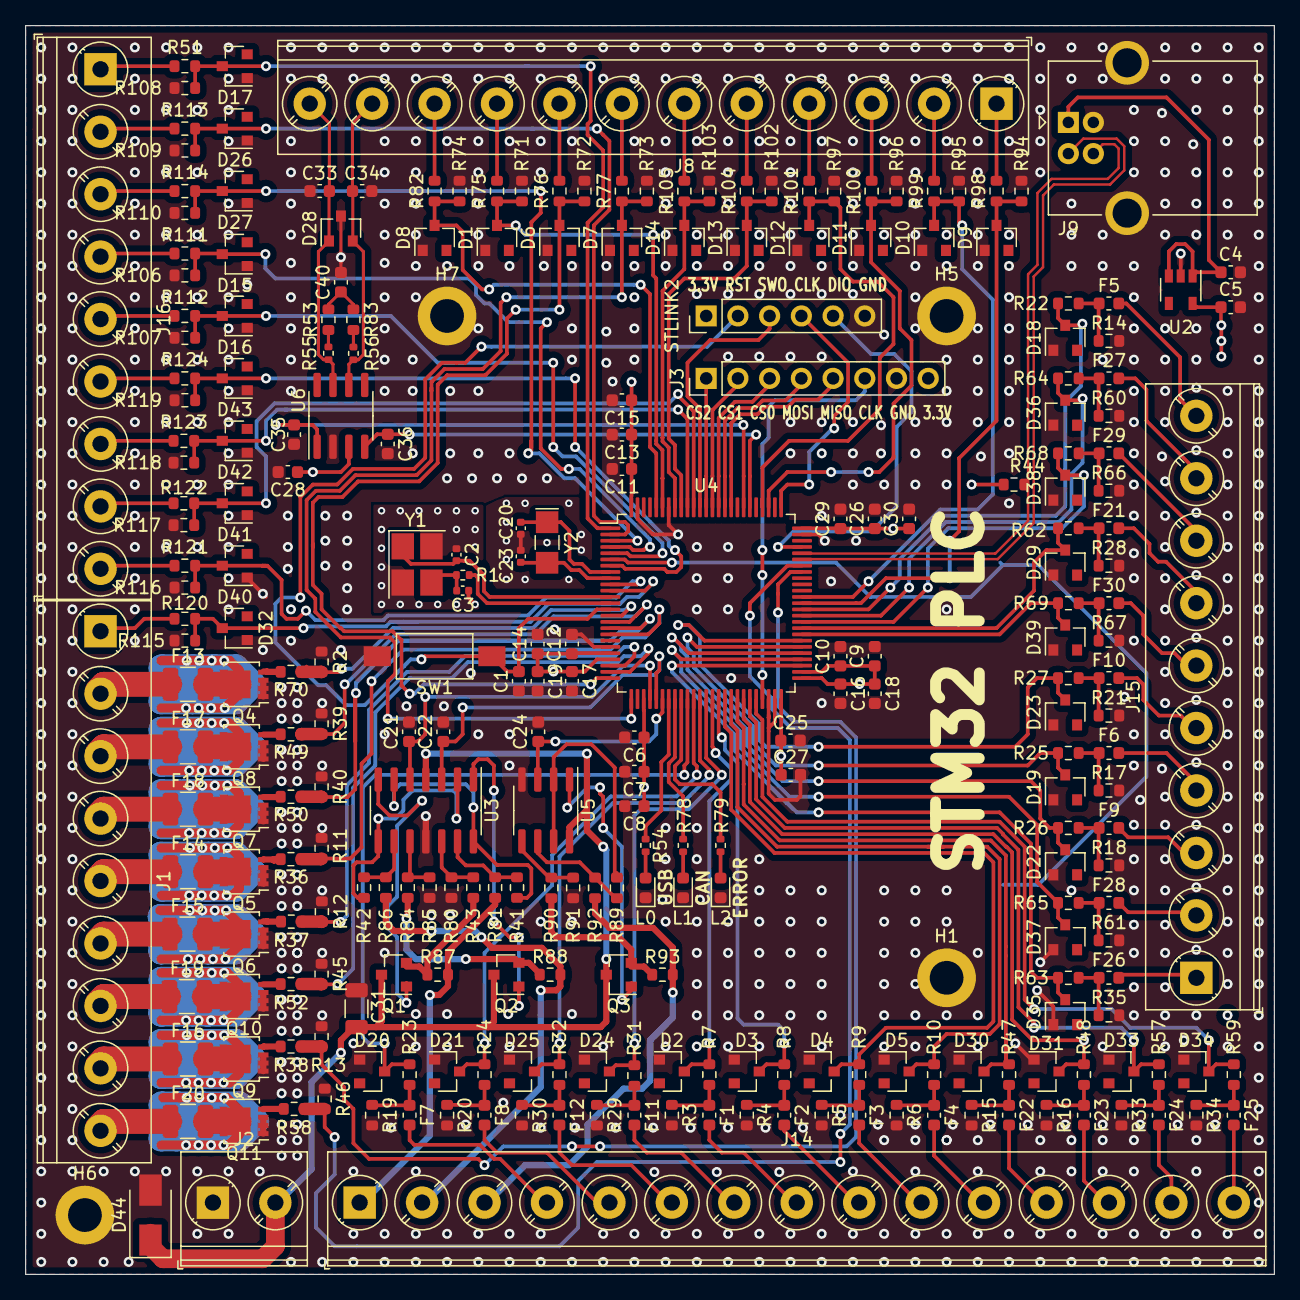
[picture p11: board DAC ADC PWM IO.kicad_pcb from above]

Board: 4 copper layers, 100.0 x 100.0 mm, 270 parts (1 on the bottom side), 194 nets.

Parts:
BT1: Battery_Cell; BatteryHolder_Keystone_3002_1x2032
C1, C6, C7, C11, C13, C21, C22, C24, C26, C29: 100nF; C_0603_1608Metric
C2, C3: 10pF; C_0402_1005Metric
C4, C5, C9, C14, C18, C19, C27: 1uF; C_0603_1608Metric
C8, C15, C30: 4.7uF; C_0603_1608Metric
C10, C12, C16, C17, C25, C28, C33, C34, C35, C36, C40: 10nF; C_0603_1608Metric
C20, C23: 4.7pF; C_0402_1005Metric
C31: 10uF; C_1206_3216Metric
D1, D2, D3, D4, D5, D6, D7, D8, D9, D10, D11, D12, D13, D14, D15, D16, D17, D18, D19, D20, D21, D22, D23, D24, D25, D26, D27, D29, D30, D31, D32, D33, D34, D35, D36, D37, D38, D39, D40, D41, D42, D43: BZX84C3V6LT1G; D_SOT-23_ANK
D28: PESD5V0L2BT,215; SOT-23
D44: SK56A-LTP; D_SMA
F1, F2, F3, F4, F5, F6, F7, F8, F9, F10, F11, F12, F21, F22, F23, F24, F25, F26, F27, F28, F29, F30: Max 30mA; Fuse_0603_1608Metric
F13, F14, F15, F16, F17, F18, F19, F20: Max 2.5A; Fuse_1210_3225Metric
H1, H5, H6, H7: MountingHole_Pad; MountingHole_2.7mm_M2.5_DIN965_Pad
J1, J16: Screw_Terminal_01x9; TerminalBlock_Phoenix_PT-1,5-9-5.0-H_1x09_P5.00mm_Horizontal
J2: Screw_Terminal_01x02; TerminalBlock_Phoenix_PT-1,5-2-5.0-H_1x02_P5.00mm_Horizontal
J3: Conn_01x08; PinHeader_1x08_P2.54mm_Vertical
J8: Screw_Terminal_01x12; TerminalBlock_Phoenix_PT-1,5-12-5.0-H_1x12_P5.00mm_Horizont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
J9: USB_B; USB_B_OST_USB-B1HSxx_Horizontal
J14: Screw_Terminal_01x15; TerminalBlock_Phoenix_PT-1,5-15-5.0-H_1x15_P5.00mm_Horizont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
J15: Screw_Terminal_01x10; TerminalBlock_Phoenix_PT-1,5-10-5.0-H_1x10_P5.00mm_Horizont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
L0: LED_USB_RX_TX; LED_0603_1608Metric
L1: LED_CAN_RX_TX; LED_0603_1608Metric
L2: LED_ERROR; LED_0603_1608Metric
Q1, Q2, Q3: BC847C-QR; SOT-23
Q4, Q5, Q6, Q7, Q8, Q9, Q10, Q11: BUK9M15-60EX; LFPAK33
R1: 2k; R_0402_1005Metric
R2, R11, R12, R13, R39, R40, R41, R42, R43, R45, R46, R51, R62, R71, R72, R73, R74, R75, R76, R77, R80, R81, R82, R84, R85, R86, R89, R90, R91, R92, R94, R95, R96, R97, R98, R99, R100, R101, R102, R103, R104, R105, R106, R107, R108, R109, R110, R111, R112, R113, R114, R115, R116, R117, R118, R119, R120, R121, R122, R123, R124: 10k; R_0603_1608Metric
R3, R4, R5, R6, R7, R8, R9, R10, R14, R15, R16, R17, R18, R19, R20, R21, R22, R23, R24, R25, R26, R27, R28, R29, R30, R31, R32, R33, R34, R35, R36, R37, R38, R47, R48, R49, R50, R52, R57, R58, R59, R60, R61, R63, R64, R65, R66, R67, R68, R69, R70, R87, R88, R93: 160; R_0603_1608Metric
R44: 1.5k; R_0603_1608Metric
R53, R83: 60; R_0603_1608Metric
R54, R78, R79: 220; R_0402_1005Metric
R55, R56: 0; R_0402_1005Metric
STLINK2: ST-Link V2 connetor; PinHeader_1x06_P2.54mm_Vertical
SW1: SW_Push; SW_SPST_FSMSM
U2: AP7343-33W5-7; SOT-23-5
U3: LM2902; SOIC-14_3.9x8.7mm_P1.27mm
U4: STM32F373VBTx; LQFP-100_14x14mm_P0.5mm
U5: LM2904; SOIC-8_3.9x4.9mm_P1.27mm
U6: TCAN332; SOIC-8_3.9x4.9mm_P1.27mm
Y1: HSE; Crystal_SMD_3225-4Pin_3.2x2.5mm_HandSoldering
Y2: LSE; Crystal_SMD_EuroQuartz_EQ161-2Pin_3.2x1.5mm_HandSoldering

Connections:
+3V3: C5.1, C6.1, C7.1, C8.1, C9.1, C10.1, C11.1, C12.1, C13.1, C14.1, C15.1, C16.1, C17.1, C18.1, C19.1, C25.1, C26.1, C27.1, C28.1, C29.1, C30.1, J3.8, R44.2, STLINK2.1, U2.5, U4.21, U4.22, U4.28, U4.50, U4.51, U4.52, U4.75, U4.100, U6.3
+5V: C4.1, J9.1, U2.1, U2.3
/CAN/CAN+: C33.2, D28.1, J8.12, R55.1, U6.7
/CAN/CAN-: C34.1, D28.2, J8.11, R56.2, U6.6
/DAC/AO0: J14.1, R81.2, R87.2
/DAC/AO1: J14.2, R86.2, R88.2
/DAC/AO2: J14.3, R92.2, R93.2
/DSDADC/DAI0M: F28.2, J15.2
/DSDADC/DAI0P: F26.2, J15.1
/DSDADC/DAI1M: F6.2, J15.4
/DSDADC/DAI1P: F9.2, J15.3
/DSDADC/DAI2M: F30.2, J15.6
/DSDADC/DAI2P: F10.2, J15.5
/DSDADC/DAI3M: F29.2, J15.8
/DSDADC/DAI3P: F21.2, J15.7
/DSDADC/DAI4M: F5.2, J15.10
/DSDADC/DAI4P: F27.2, J15.9
/Digital/P0: F13.1, J1.2
/Digital/P1: F17.1, J1.3
/Digital/P2: F18.1, J1.4
/Digital/P3: F14.1, J1.5
/Digital/P4: F15.1, J1.6
/Digital/P5: F19.1, J1.7
/Digital/P6: F16.1, J1.8
/Digital/P7: F20.1, J1.9
/INPUT/DI0: J16.1, R51.2
/INPUT/DI1: J16.2, R113.2
/INPUT/DI2: J16.3, R114.2
/INPUT/DI3: J16.4, R111.2
/INPUT/DI4: J16.5, R112.2
/INPUT/DI5: J16.6, R124.2
/INPUT/DI6: J16.7, R123.2
/INPUT/DI7: J16.8, R122.2
/INPUT/DI8: J16.9, R121.2
/INPUT/DI9: J1.1, R120.2
/Pulse/E0+: J8.6, R105.2
/Pulse/E0-: J8.5, R104.2
/Pulse/E1+: J8.4, R101.2
/Pulse/E1-: J8.3, R100.2
/Pulse/E2+: J8.2, R99.2
/Pulse/E2-: J8.1, R98.2
/Pulse/IC0: J8.10, R82.2
/Pulse/IC1: J8.9, R75.2
/Pulse/IC2: J8.8, R76.2
/Pulse/IC3: J8.7, R77.2
/SDADC/AI0: F7.2, J14.4
/SDADC/AI1: F8.2, J14.5
/SDADC/AI2: F12.2, J14.6
/SDADC/AI3: F11.2, J14.7
/SDADC/AI4: F1.2, J14.8
/SDADC/AI5: F2.2, J14.9
/SDADC/AI6: F3.2, J14.10
/SDADC/AI7: F4.2, J14.11
/SDADC/AI8: F22.2, J14.12
/SDADC/AI9: F23.2, J14.13
/SDADC/AI10: F24.2, J14.14
/SDADC/AI11: F25.2, J14.15
GND: BT1.2, C1.1, C2.1, C3.1, C4.2, C5.2, C6.2, C7.2, C8.2, C9.2, C10.2, C11.2, C12.2, C13.2, C14.2, C15.2, C16.2, C17.2, C18.2, C19.2, C20.1, C21.2, C22.2, C23.1, C24.2, C25.2, C26.2, C27.2, C28.2, C29.2, C30.2, C31.2, C33.1, C34.2, C35.1, C36.2, C40.2, D1.2, D2.2, D3.2, D4.2, D5.2, D6.2, D7.2, D8.2, D9.2, D10.2, D11.2, D12.2, D13.2, D14.2, D15.2, D16.2, D17.2, D18.2, D19.2, D20.2, D21.2, D22.2, D23.2, D24.2, D25.2, D26.2, D27.2, D28.3, D29.2, D30.2, D31.2, D32.2, D33.2, D34.2, D35.2, D36.2, D37.2, D38.2, D39.2, D40.2, D41.2, D42.2, D43.2, D44.2, H1.1, H5.1, H6.1, H7.1, J2.1, J3.7, J9.4, J9.5, L0.1, L1.1, L2.1, Q4.1, Q4.2, Q4.3, Q5.1, Q5.2, Q5.3, Q6.1, Q6.2, Q6.3, Q7.1, Q7.2, Q7.3, Q8.1, Q8.2, Q8.3, Q9.1, Q9.2, Q9.3, Q10.1, Q10.2, Q10.3, Q11.1, Q11.2, Q11.3, R2.2, R3.2, R4.2, R5.2, R6.2, R11.2, R12.2, R13.2, R14.2, R15.2, R16.2, R17.2, R18.2, R19.2, R20.2, R21.2, R28.2, R29.2, R30.2, R33.2, R34.2, R35.2, R39.2, R40.2, R45.2, R46.2, R60.2, R61.2, R66.2, R67.2, R71.1, R72.1, R73.1, R74.1, R80.1, R85.1, R91.1, R94.1, R95.1, R96.1, R97.1, R102.1, R103.1, R106.1, R107.1, R108.1, R109.1, R110.1, R115.1, R116.1, R117.1, R118.1, R119.1, STLINK2.6, SW1.1, U2.2, U3.11, U4.20, U4.48, U4.49, U4.74, U4.94, U4.99, U5.4, U6.2, Y1.2, Y1.4
NRST: C1.2, STLINK2.2, SW1.2, U4.14
unnamed: BT1.1, U4.6
unnamed: C3.2, R1.1, Y1.3
unnamed: C40.1, R53.2, R83.1
unnamed: F1.1, R3.1, R7.1
unnamed: F2.1, R4.1, R8.1
unnamed: F3.1, R5.1, R9.1
unnamed: F4.1, R6.1, R10.1
unnamed: F5.1, R14.1, R22.1
unnamed: F6.1, R17.1, R25.1
unnamed: F7.1, R19.1, R23.1
unnamed: F8.1, R20.1, R24.1
unnamed: F9.1, R18.1, R26.1
unnamed: F10.1, R21.1, R27.1
unnamed: F11.1, R29.1, R31.1
unnamed: F12.1, R30.1, R32.1
unnamed: F13.2, Q4.5
unnamed: F14.2, Q5.5
unnamed: F15.2, Q6.5
unnamed: F16.2, Q9.5
unnamed: F17.2, Q8.5
unnamed: F18.2, Q7.5
unnamed: F19.2, Q10.5
unnamed: F20.2, Q11.5
unnamed: F21.1, R28.1, R62.1
unnamed: F22.1, R15.1, R47.1
unnamed: F23.1, R16.1, R48.1
unnamed: F24.1, R33.1, R57.1
unnamed: F25.1, R34.1, R59.1
unnamed: F26.1, R35.1, R63.1
unnamed: F27.1, R60.1, R64.1
unnamed: F28.1, R61.1, R65.1
unnamed: F29.1, R66.1, R68.1
unnamed: F30.1, R67.1, R69.1
unnamed: L0.2, R54.2
unnamed: L1.2, R78.2
unnamed: L2.2, R79.2
unnamed: Q1.1, U3.7
unnamed: Q1.2, R43.2, R87.1
unnamed: Q2.1, U3.1
unnamed: Q2.2, R84.2, R88.1
unnamed: Q3.1, U5.1
unnamed: Q3.2, R90.2, R93.1
unnamed: Q4.4, R70.2
unnamed: Q5.4, R36.2
unnamed: Q6.4, R37.2
unnamed: Q7.4, R50.2
unnamed: Q8.4, R49.2
unnamed: Q9.4, R38.2
unnamed: Q10.4, R52.2
unnamed: Q11.4, R58.2
unnamed: R41.1, U3.6, U3.14
unnamed: R41.2, R81.1, U3.13
unnamed: R42.1, U3.2, U3.8
unnamed: R42.2, R86.1, U3.9
unnamed: R43.1, R80.2, U3.12
unnamed: R53.1, R55.2
unnamed: R56.1, R83.2
unnamed: R84.1, R85.2, U3.10
unnamed: R89.1, U5.2, U5.7
unnamed: R89.2, R92.1, U5.6
unnamed: R90.1, R91.2, U5.5
PA0: R12.1, R37.1, U4.23
PA1: R45.1, R52.1, U4.24
PA2: D6.1, R72.2, R76.1, U4.25
PA3: D7.1, R73.2, R77.1, U4.26
PA4: C21.1, U3.5, U4.29
PA5: C22.1, U3.3, U4.30
PA6: C24.1, U4.31, U5.3
PA7: R54.1, U4.32
PA9: R13.1, R38.1, U4.68
PA10: R46.1, R58.1, U4.69
PA13: STLINK2.5, U4.72
PA14: STLINK2.4, U4.76
PB0: D20.1, R23.2, U4.35
PB1: D21.1, R24.2, U4.36
PB2: D25.1, R32.2, U4.37
PB3: STLINK2.3, U4.89
PB4: D41.1, R117.2, R122.1, U4.90
PB5: D42.1, R118.2, R123.1, U4.91
PB6: D13.1, R102.2, R104.1, U4.92
PB7: D14.1, R103.2, R105.1, U4.93
PB8: D1.1, R71.2, R75.1, U4.95
PB9: D8.1, R74.2, R82.1, U4.96
PB10: J3.6, U4.47
PB14: D35.1, R63.2, U4.53
PB15: D37.1, R65.2, U4.54
PC0: R2.1, R70.1, U4.15
PC1: R39.1, R49.1, U4.16
PC2: R40.1, R50.1, U4.17
PC3: R11.1, R36.1, U4.18
PC4: R78.1, U4.33
PC5: R79.1, U4.34
PC6: D9.1, R94.2, R98.1, U4.63
PC7: D10.1, R95.2, R99.1, U4.64
PC10: D11.1, R96.2, R100.1, U4.78
PC11: D12.1, R97.2, R101.1, U4.79
PC13: D43.1, R119.2, R124.1, U4.7
PC14: C20.2, U4.8, Y2.1
PC15: C23.2, U4.9, Y2.2
PD0: C36.1, U4.81, U6.4
PD1: C35.2, U4.82, U6.1
PD3: J3.5, U4.84
PD4: J3.4, U4.85
PD5: J3.3, U4.86
PD6: J3.2, U4.87
PD7: J3.1, U4.88
PD8: D22.1, R26.2, U4.55
PD9: D19.1, R25.2, U4.56
PD10: D23.1, R27.2, U4.57
PD11: D39.1, R69.2, U4.58
PD12: D29.1, R62.2, U4.59
PD13: D38.1, R68.2, U4.60
PD14: D36.1, R64.2, U4.61
PD15: D18.1, R22.2, U4.62
PE2: D17.1, R51.1, R108.2, U4.1
PE3: D26.1, R109.2, R113.1, U4.2
PE4: D27.1, R110.2, R114.1, U4.3
PE5: D15.1, R106.2, R111.1, U4.4
PE6: D16.1, R107.2, R112.1, U4.5
PE7: D24.1, R31.2, U4.38
PE8: D2.1, R7.2, U4.39
PE9: D3.1, R8.2, U4.40
PE10: D4.1, R9.2, U4.41
PE11: D5.1, R10.2, U4.42
PE12: D30.1, R47.2, U4.43
PE13: D31.1, R48.2, U4.44
PE14: D33.1, R57.2, U4.45
PE15: D34.1, R59.2, U4.46
PF0: C2.2, U4.12, Y1.1
PF1: R1.2, U4.13
PF9: D40.1, R116.2, R121.1, U4.10
PF10: D32.1, R115.2, R120.1, U4.11
USB+: J9.3, R44.1, U4.71
USB-: J9.2, U4.70
VDC: C31.1, D44.1, J2.2, Q1.3, Q2.3, Q3.3, U3.4, U5.8

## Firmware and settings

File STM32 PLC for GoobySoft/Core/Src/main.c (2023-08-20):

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
/* Includes ------------------------------------------------------------------*/
#include "main.h"
#include "usb_device.h"

/* USER CODE BEGIN Includes */
#include "STM32 PLC/Touch Screen/Touch_screen.h"
#include "STM32 PLC/Touch Screen/Hardware/ILI9341.h"
/* USER CODE END Includes */

CAN_HandleTypeDef hcan;

DAC_HandleTypeDef hdac1;
DAC_HandleTypeDef hdac2;

RTC_HandleTypeDef hrtc;

SDADC_HandleTypeDef hsdadc1;
SDADC_HandleTypeDef hsdadc2;
SDADC_HandleTypeDef hsdadc3;
DMA_HandleTypeDef hdma_sdadc1;
DMA_HandleTypeDef hdma_sdadc2;
DMA_HandleTypeDef hdma_sdadc3;

SPI_HandleTypeDef hspi2;

TIM_HandleTypeDef htim2;
TIM_HandleTypeDef htim3;
TIM_HandleTypeDef htim4;
TIM_HandleTypeDef htim5;
TIM_HandleTypeDef htim6;
TIM_HandleTypeDef htim12;
TIM_HandleTypeDef htim13;
TIM_HandleTypeDef htim15;
TIM_HandleTypeDef htim16;
TIM_HandleTypeDef htim17;
TIM_HandleTypeDef htim19;
DMA_HandleTypeDef hdma_tim15_ch1_up_trig_com;
DMA_HandleTypeDef hdma_tim16_ch1_up;
DMA_HandleTypeDef hdma_tim17_ch1_up;

/* USER CODE BEGIN PV */
ILI9341_SPI lcd = {0};
/* USER CODE END PV */

void SystemClock_Config(void);
static void MX_GPIO_Init(void);
static void MX_DMA_Init(void);
static void MX_DAC2_Init(void);
static void MX_TIM2_Init(void);
static void MX_TIM5_Init(void);
static void MX_TIM4_Init(void);
static void MX_SDADC1_Init(void);
static void MX_SDADC2_Init(void);
static void MX_SDADC3_Init(void);
static void MX_CAN_Init(void);
static void MX_TIM6_Init(void);
static void MX_TIM12_Init(void);
static void MX_TIM13_Init(void);
static void MX_TIM16_Init(void);
static void MX_TIM17_Init(void);
static void MX_DAC1_Init(void);
static void MX_TIM19_Init(void);
static void MX_TIM3_Init(void);
static void MX_TIM15_Init(void);
static void MX_SPI2_Init(void);
static void MX_RTC_Init(void);
/**
  * @brief  The application entry point.
  * @retval int
  */
int main(void)
{
  /* MCU Configuration--------------------------------------------------------*/

  /* Reset of all peripherals, Initializes the Flash interface and the Systick. */
  HAL_Init();

  /* Configure the system clock */
  SystemClock_Config();

  /* Initialize all configured peripherals */
  MX_GPIO_Init();
  MX_DMA_Init();
  MX_DAC2_Init();
  MX_TIM2_Init();
  MX_TIM5_Init();
  MX_TIM4_Init();
  MX_SDADC1_Init();
  MX_SDADC2_Init();
  MX_SDADC3_Init();
  MX_CAN_Init();
  MX_TIM6_Init();
  MX_TIM12_Init();
  MX_TIM13_Init();
  MX_TIM16_Init();
  MX_USB_DEVICE_Init();
  MX_TIM17_Init();
  MX_DAC1_Init();
  MX_TIM19_Init();
  MX_TIM3_Init();
  MX_TIM15_Init();
  MX_SPI2_Init();
  MX_RTC_Init();
  /* USER CODE BEGIN 2 */

  /* !!!Notice that   MX_DMA_Init(); must be after   MX_GPIO_Init(); !!! */

  /* Start PLC */
  STM32_PLC_Analog_Input(&htim12, &htim13, &hsdadc1, &hsdadc2, &hsdadc3);
  STM32_PLC_Analog_Output(&hdac1, &hdac2, &htim6);
  STM32_PLC_Encoder(&htim4, &htim19, &htim3);
  STM32_PLC_Input_Capture(&htim17, &htim16, &htim15);
  STM32_PLC_PWM(&htim2, &htim5);
  STM32_PLC_CAN(&hcan);
  STM32_PLC_RTC(&hrtc);
  STM32_PLC_LCD(&hspi2, &hspi2, CS0_GPIO_Port, CS0_Pin, CS1_GPIO_Port, CS1_Pin, CS2_GPIO_Port, CS2_Pin);
  STM32_PLC_LED();

  /* Start Open SAE J1939 */
  J1939 j1939 = {0};
  Open_SAE_J1939_Startup_ECU(&j1939);
  STM32_PLC_Flash_Get_J1939_This_ECU_Address(&j1939.information_this_ECU.this_ECU_address);

  /* USER CODE END 2 */

  /* Infinite loop */
  /* USER CODE BEGIN WHILE */
  uint8_t frame_id = 0;
  STM32_PLC_LCD_Show_Main_Frame(&frame_id, false);
  while (1)
  {
    /* USER CODE END WHILE */

    /* USER CODE BEGIN 3 */
	  STM32_PLC_LCD_Call_Main_Logic(&frame_id, &j1939);
  }
  /* USER CODE END 3 */
}

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


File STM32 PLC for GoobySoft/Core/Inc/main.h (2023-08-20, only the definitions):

#define DI0_Pin GPIO_PIN_2
#define DI0_GPIO_Port GPIOE
#define DI1_Pin GPIO_PIN_3
#define DI1_GPIO_Port GPIOE
#define DI2_Pin GPIO_PIN_4
#define DI2_GPIO_Port GPIOE
#define DI3_Pin GPIO_PIN_5
#define DI3_GPIO_Port GPIOE
#define DI4_Pin GPIO_PIN_6
#define DI4_GPIO_Port GPIOE
#define DI5_Pin GPIO_PIN_13
#define DI5_GPIO_Port GPIOC
#define DI8_Pin GPIO_PIN_9
#define DI8_GPIO_Port GPIOF
#define DI9_Pin GPIO_PIN_10
#define DI9_GPIO_Port GPIOF
#define PWM0_Pin GPIO_PIN_0
#define PWM0_GPIO_Port GPIOC
#define PWM1_Pin GPIO_PIN_1
#define PWM1_GPIO_Port GPIOC
#define PWM2_Pin GPIO_PIN_2
#define PWM2_GPIO_Port GPIOC
#define PWM3_Pin GPIO_PIN_3
#define PWM3_GPIO_Port GPIOC
#define PWM4_Pin GPIO_PIN_0
#define PWM4_GPIO_Port GPIOA
#define PWM5_Pin GPIO_PIN_1
#define PWM5_GPIO_Port GPIOA
#define IC2_Pin GPIO_PIN_2
#define IC2_GPIO_Port GPIOA
#define IC3_Pin GPIO_PIN_3
#define IC3_GPIO_Port GPIOA
#define AO0_Pin GPIO_PIN_4
#define AO0_GPIO_Port GPIOA
#define AO1_Pin GPIO_PIN_5
#define AO1_GPIO_Port GPIOA
#define AO2_Pin GPIO_PIN_6
#define AO2_GPIO_Port GPIOA
#define LED_USB_Pin GPIO_PIN_7
#define LED_USB_GPIO_Port GPIOA
#define LED_CAN_Pin GPIO_PIN_4
#define LED_CAN_GPIO_Port GPIOC
#define LED_ERROR_Pin GPIO_PIN_5
#define LED_ERROR_GPIO_Port GPIOC
#define AI0_Pin GPIO_PIN_0
#define AI0_GPIO_Port GPIOB
#define AI1_Pin GPIO_PIN_1
#define AI1_GPIO_Port GPIOB
#define AI2_Pin GPIO_PIN_2
#define AI2_GPIO_Port GPIOB
#define AI3_Pin GPIO_PIN_7
#define AI3_GPIO_Port GPIOE
#define AI4_Pin GPIO_PIN_8
#define AI4_GPIO_Port GPIOE
#define AI5_Pin GPIO_PIN_9
#define AI5_GPIO_Port GPIOE
#define AI6_Pin GPIO_PIN_10
#define AI6_GPIO_Port GPIOE
#define AI7_Pin GPIO_PIN_11
#define AI7_GPIO_Port GPIOE
#define AI8_Pin GPIO_PIN_12
#define AI8_GPIO_Port GPIOE
#define AI9_Pin GPIO_PIN_13
#define AI9_GPIO_Port GPIOE
#define AI10_Pin GPIO_PIN_14
#define AI10_GPIO_Port GPIOE
#define AI11_Pin GPIO_PIN_15
#define AI11_GPIO_Port GPIOE
#define DAI0P_Pin GPIO_PIN_14
#define DAI0P_GPIO_Port GPIOB
#define DAI0M_Pin GPIO_PIN_15
#define DAI0M_GPIO_Port GPIOB
#define DAI1P_Pin GPIO_PIN_8
#define DAI1P_GPIO_Port GPIOD
#define DAI1M_Pin GPIO_PIN_9
#define DAI1M_GPIO_Port GPIOD
#define DAI2P_Pin GPIO_PIN_10
#define DAI2P_GPIO_Port GPIOD
#define DAI2M_Pin GPIO_PIN_11
#define DAI2M_GPIO_Port GPIOD
#define DAI3P_Pin GPIO_PIN_12
#define DAI3P_GPIO_Port GPIOD
#define DAI3M_Pin GPIO_PIN_13
#define DAI3M_GPIO_Port GPIOD
#define DAI4P_Pin GPIO_PIN_14
#define DAI4P_GPIO_Port GPIOD
#define DAI4M_Pin GPIO_PIN_15
#define DAI4M_GPIO_Port GPIOD
#define E2__Pin GPIO_PIN_6
#define E2__GPIO_Port GPIOC
#define E2_C7_Pin GPIO_PIN_7
#define E2_C7_GPIO_Port GPIOC
#define PWM6_Pin GPIO_PIN_9
#define PWM6_GPIO_Port GPIOA
#define PWM7_Pin GPIO_PIN_10
#define PWM7_GPIO_Port GPIOA
#define E1__Pin GPIO_PIN_10
#define E1__GPIO_Port GPIOC
#define E1_C11_Pin GPIO_PIN_11
#define E1_C11_GPIO_Port GPIOC
#define CS0_Pin GPIO_PIN_5
#define CS0_GPIO_Port GPIOD
#define CS1_Pin GPIO_PIN_6
#define CS1_GPIO_Port GPIOD
#define CS2_Pin GPIO_PIN_7
#define CS2_GPIO_Port GPIOD
#define DI7_Pin GPIO_PIN_4
#define DI7_GPIO_Port GPIOB
#define DI6_Pin GPIO_PIN_5
#define DI6_GPIO_Port GPIOB
#define E0__Pin GPIO_PIN_6
#define E0__GPIO_Port GPIOB
#define E0_B7_Pin GPIO_PIN_7
#define E0_B7_GPIO_Port GPIOB
#define IC1_Pin GPIO_PIN_8
#define IC1_GPIO_Port GPIOB
#define IC0_Pin GPIO_PIN_9
#define IC0_GPIO_Port GPIOB

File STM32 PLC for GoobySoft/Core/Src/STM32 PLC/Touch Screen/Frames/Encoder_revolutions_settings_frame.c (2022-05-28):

/*
 * Encoder_revolutions_settings_frame.c
 *
 *  Created on: 25 juli 2021
 *      Author: Daniel Mårtensson
 */

#include "../Touch_screen.h"
#include "../Hardware/ILI9341.h"
#include "../../Functions.h"

void STM32_PLC_LCD_Show_Encoder_Revolutions_Settings_Frame(uint8_t *frame_id) {
	/* Clear the screen , but not the icons */
	ILI9341_fill_rect(51, 6, 314, 234, COLOR_NAVY);

	/* Write the title */
	ILI9341_draw_horizontal_line(50, 30, 265, COLOR_GREEN);
	ILI9341_print_text("Set encoder revolution", 55, 10, COLOR_YELLOW, COLOR_NAVY, 1);

	/* Show all calibration inputs */
	ILI9341_print_text("Encoder counts between:", 55, 35, COLOR_YELLOW, COLOR_NAVY, 1);
	ILI9341_print_text("-32768 to 32767", 55, 45, COLOR_YELLOW, COLOR_NAVY, 1);
	ILI9341_print_text("Set how many pulses one", 55, 55, COLOR_YELLOW, COLOR_NAVY, 1);
	ILI9341_print_text("revolution is for encoder:", 55, 65, COLOR_YELLOW, COLOR_NAVY, 1);

	/* Show selected frequency */
	char text[50];
	ILI9341_print_text("Current settings:", 55, 75, COLOR_YELLOW, COLOR_NAVY, 1);
	uint16_t pulses0, pulses1, pulses2;
	STM32_PLC_Encoder_Get_Calibration(0, &pulses0);
	STM32_PLC_Encoder_Get_Calibration(1, &pulses1);
	STM32_PLC_Encoder_Get_Calibration(2, &pulses2);
	sprintf(text, "Encoder0:%i Encoder1:%i Encoder2:%i", pulses0, pulses1, pulses2);
	ILI9341_print_text(text, 55, 85, COLOR_YELLOW, COLOR_NAVY, 1);

	/* Select settings button */
	ILI9341_fill_rect(90, 195, 273, 220, COLOR_GREEN);
	ILI9341_hollow_rect(90, 195, 273, 220, COLOR_BLACK);
	ILI9341_print_text("Select encoder", 100, 200, COLOR_BLACK, COLOR_GREEN, 2);

	/* Logic for request button */
	STM32_PLC_LCD_Call_One_Button_Logic(90, 195, 273, 220);

	/* Ask the user if */
	if(STM32_PLC_LCD_Show_Question_Yes_No_Dialog("Do you want to set encoder revolution?") == 0) {
		STM32_PLC_LCD_Show_Main_Frame(frame_id, false);
		return;
	}

	/* You entered choice 1 - Show numpad */
	bool minusbutton_show = false;
	bool decimalbutton_show = false;
	float number_value;
	if(STM32_PLC_LCD_Show_Numpad_Frame(decimalbutton_show, minusbutton_show, &number_value, "Enter input number between 1 and 65535") == 0) {
		STM32_PLC_LCD_Show_Main_Frame(frame_id, false);
		return;
	}

	/* Check */
	uint16_t pulses_per_revolution;
	if(number_value < 1)
		pulses_per_revolution = 1;
	else if(number_value > 65535)
		pulses_per_revolution = 65535;
	else
		pulses_per_revolution = (uint16_t) number_value;

	/* Ask for which PWM */
	if(STM32_PLC_LCD_Show_Numpad_Frame(decimalbutton_show, minusbutton_show, &number_value, "Set setting for Encoder0=0, Encoder1=1, Encoder2=2") == 0) {
		STM32_PLC_LCD_Show_Main_Frame(frame_id, false);
		return;
	}

	/* Check */
	uint8_t encoder_choice;
	if(number_value < 0)
		encoder_choice = 0;
	else if(number_value > 2)
		encoder_choice = 2;
	else
		encoder_choice = (uint8_t) number_value;

	/* Apply them */
	STM32_PLC_Encoder_Set_Calibration(encoder_choice, pulses_per_revolution, true);

	/* Show main frame again */
	STM32_PLC_LCD_Show_Main_Frame(frame_id, false);
}

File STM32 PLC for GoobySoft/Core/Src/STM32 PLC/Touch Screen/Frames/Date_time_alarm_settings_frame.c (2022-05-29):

/*
 * Date_time_alarm_settings_frame.c
 *
 *  Created on: Jul 26, 2021
 *      Author: Daniel Mårtensson
 */

#include "../Touch_screen.h"
#include "../Hardware/ILI9341.h"
#include "../../Functions.h"

static uint8_t show_numpad_question(char title[], uint8_t *frame_id, uint8_t min_value, uint8_t max_value, uint8_t *value);

void STM32_PLC_LCD_Show_Date_Time_Alarm_Settings_Frame(uint8_t *frame_id) {
	/* Clear the screen , but not the icons */
	ILI9341_fill_rect(51, 6, 314, 234, COLOR_NAVY);

	/* Write the title */
	ILI9341_draw_horizontal_line(50, 30, 265, COLOR_GREEN);
	ILI9341_print_text("Configure the date and time and alarm", 55, 10, COLOR_YELLOW, COLOR_NAVY, 1);

	/* Show the current date and time */
	uint8_t year, month, week_day, date, hours, minutes, seconds;
	STM32_PLC_RTC_Get_Date(&week_day, &date, &month, &year);
	STM32_PLC_RTC_Get_Time(&seconds, &minutes, &hours);
	char text[60];
	ILI9341_print_text("Current date and time:", 55, 35, COLOR_YELLOW, COLOR_NAVY, 1);
	sprintf(text, "Date:%i-%i-%i Time:%i:%i:%i", year + 2000, month, date, hours, minutes, seconds);
	ILI9341_print_text(text, 55, 45, COLOR_YELLOW, COLOR_NAVY, 1);

	/* Print Alarm A */
	bool active = STM32_PLC_RTC_Alarm_A_Is_Activated();
	bool enabled = STM32_PLC_RTC_Alarm_A_Is_Enabled();
	STM32_PLC_RTC_Get_Alarm_A(&date, &hours, &minutes);
	ILI9341_print_text("Current alarm A:", 55, 55, COLOR_YELLOW, COLOR_NAVY, 1);
	sprintf(text, "Date:%i Time:%i:%i Active:%i Enabled:%i", date, hours, minutes, active, enabled);
	ILI9341_print_text(text, 55, 65, COLOR_YELLOW, COLOR_NAVY, 1);

	/* Print Alarm B */
	active = STM32_PLC_RTC_Alarm_B_Is_Activated();
	enabled = STM32_PLC_RTC_Alarm_B_Is_Enabled();
	STM32_PLC_RTC_Get_Alarm_B(&week_day, &hours, &minutes);
	ILI9341_print_text("Current alarm B:", 55, 75, COLOR_YELLOW, COLOR_NAVY, 1);
	sprintf(text, "Week day:%i Time:%i:%i Active:%i Enabled:%i", week_day, hours, minutes, active, enabled);
	ILI9341_print_text(text, 55, 85, COLOR_YELLOW, COLOR_NAVY, 1);

	/* Explain */
	ILI9341_print_text("Alarm A active = PWM4 to PWM7 high", 55, 95, COLOR_YELLOW, COLOR_NAVY, 1);
	ILI9341_print_text("Alarm B active = PWM0 to PWM3 high", 55, 105, COLOR_YELLOW, COLOR_NAVY, 1);

	/* Button */
	ILI9341_fill_rect(65, 195, 300, 220, COLOR_GREEN);
	ILI9341_hollow_rect(65, 195, 300, 220, COLOR_BLACK);
	ILI9341_print_text("Set date time alarm", 70, 200, COLOR_BLACK, COLOR_GREEN, 2);

	/* Logic for button */
	STM32_PLC_LCD_Call_One_Button_Logic(65, 195, 300, 220);

	/* Ask if */
	if(STM32_PLC_LCD_Show_Question_Yes_No_Dialog("Do you want to set configuration?") == 0) {
		STM32_PLC_LCD_Show_Main_Frame(frame_id, false);
		return;
	}

	/* Enable the alarm A */
	if(STM32_PLC_LCD_Show_Question_Yes_No_Dialog("Alarm A:Do you want to enable?") == 0) {
		STM32_PLC_RTC_Enable_Alarm_A(false);
	}else{
		STM32_PLC_RTC_Enable_Alarm_A(true);
	}

	/* Change the alarm */
	if(STM32_PLC_LCD_Show_Question_Yes_No_Dialog("Alarm A:Do you want to edit?") == 1) {
		if(show_numpad_question("Alarm A:Enter hours between 0 and 23", frame_id, 0, 23, &hours))
			return;
		if(show_numpad_question("Alarm A:Enter minutes between 0 and 59", frame_id, 0, 59, &minutes))
			return;
		if(show_numpad_question("Alarm A:Enter date between 1 and 31", frame_id, 1, 31, &date))
			return;

		/* Set alarm A */
		STM32_PLC_RTC_Set_Alarm_A(minutes, hours, date);
	}


	/* Enable alarm B */
	if(STM32_PLC_LCD_Show_Question_Yes_No_Dialog("Alarm B:Do you want to enable?") == 0) {
		STM32_PLC_RTC_Enable_Alarm_B(false);
	}else{
		STM32_PLC_RTC_Enable_Alarm_B(true);
	}

	/* Change the alarm */
	if(STM32_PLC_LCD_Show_Question_Yes_No_Dialog("Alarm B:Do you want to edit?") == 1) {
		if(show_numpad_question("Alarm B:Enter hours between 0 and 23", frame_id, 0, 23, &hours))
			return;
		if(show_numpad_question("Alarm B:Enter minutes between 0 and 59", frame_id, 0, 59, &minutes))
			return;
		if(show_numpad_question("Alarm B:Enter week day between 1 and 7", frame_id, 1, 7, &week_day))
			return;

		/* Set alarm B */
		STM32_PLC_RTC_Set_Alarm_B(minutes, hours, week_day);
	}

	/* Ask the user if */
	if(STM32_PLC_LCD_Show_Question_Yes_No_Dialog("Do you want to set date and time?") == 0) {
		STM32_PLC_LCD_Show_Main_Frame(frame_id, false);
		return;
	}

	/* Enter date and time */
	if(show_numpad_question("Enter year between 0 and 99", frame_id, 0, 99, &year))
		return;
	if(show_numpad_question("Enter month between 1 and 12", frame_id, 1, 11, &month))
		return;
	if(show_numpad_question("Enter week day between 1 and 7", frame_id, 1, 7, &week_day))
		return;
	if(show_numpad_question("Enter date between 1 and 31", frame_id, 1, 31, &date))
		return;
	if(show_numpad_question("Enter hours between 0 and 23", frame_id, 0, 23, &hours))
		return;
	if(show_numpad_question("Enter minutes between 0 and 59", frame_id, 0, 59, &minutes))
		return;

	/* Set date and time where seconds is 0 */
	STM32_PLC_RTC_Set_Date(date, week_day, month, year);
	STM32_PLC_RTC_Set_Time(0, minutes, hours);

	/* Exit */
	STM32_PLC_LCD_Show_Main_Frame(frame_id, false);
}

static uint8_t show_numpad_question(char title[], uint8_t *frame_id, uint8_t min_value, uint8_t max_value, uint8_t *value){
	bool minusbutton_show = false;
	bool decimalbutton_show = false;
	float number_value;
	if(STM32_PLC_LCD_Show_Numpad_Frame(decimalbutton_show, minusbutton_show, &number_value, title) == 0) {
		STM32_PLC_LCD_Show_Main_Frame(frame_id, false);
		return 1;
	}
	if(number_value < min_value)
		*value = min_value;
	else if(number_value > max_value)
		*value = max_value;
	else
		*value = (uint32_t) number_value;
	return 0;
}

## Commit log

2022-05-30 Add blueprints for shell
    [Bottom.dxf, Top.dxf]
2022-05-31 LCD holder
    [LCD holder.dxf]
2022-12-20 Update CAN-bus configuration
    [CAN.kicad_sch, DAC ADC PWM IO.kicad_pcb, DAC ADC PWM IO.kicad_sch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]

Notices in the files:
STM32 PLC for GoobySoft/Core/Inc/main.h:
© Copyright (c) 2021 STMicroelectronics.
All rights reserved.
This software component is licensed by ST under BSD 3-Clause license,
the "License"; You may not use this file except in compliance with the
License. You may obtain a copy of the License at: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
